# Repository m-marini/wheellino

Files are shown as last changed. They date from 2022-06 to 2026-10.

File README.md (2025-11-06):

Wheelly is a wheels robot.

The robot consits of

- Chassis with two lateral wheels driven by 2 x DC motors and a free wheel.
- 2 x IR speed sensors for the wheels
- Motor controller board L298N
- 12V DC rechargable motors Li battery
- 5V DC rechargable controller Li battery
- Power supply module 3.3V
- MPU6050 gyroscope module
- ESP32 Vroom main controller board
- SG90 Microservo
- 2 x Lidar sensors
- 6 x microswitch contact sensors
- LCD Display
- Wifi-Camera

The ESP32 controller is driving all the units to allow the robot to collect the sensor data, compute the position relative the initial state, drive the proxcimity sensor direction, drive the robot for a specific direction and speed by feeding back from gyroscpe and speed sensors and comunicate with remote server via wifi sending status and receiving commands.

Documentation in [Wiki](https://github.com/m-marini/wheellino/wiki)

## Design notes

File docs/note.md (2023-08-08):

# Note

Progetti di test:

- [x] Test MPU
- [x] Test Servo
- [x] Test Sensore SR04
- [ ] Test Motori + sensori motori
- [ ] Test sensori di contatto
- [ ] Test Display

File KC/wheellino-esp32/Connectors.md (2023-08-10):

# Connectors

### J1 - SR04 Proximity Sensor

| PIN |  Color | Description |
|----:|---|---|
| 1 | Yellow | 5V |
| 2 | Orange | Trigger |
| 3 | Red | Echo |
| 4 | Brown  | Gnd |

### J2 - Servo

| PIN |  Color | Description |
|----:|---|---|
| 1 | Brown  | Gnd |
| 2 | Red | 5V |
| 3 | Orange | PWM |

### J3 - Motor Drivers

| PIN |  Color | Description |
|----:|---|---|
| 1 | Brown  | LF |
| 2 | Red | 5V |
| 3 | Orange | LB |
| 4 | Yellow | Gnd |
| 5 | Green  | RB |
| 6 | Blue | Gnd |
| 7 | Purple | RF |
| 8 | White  | 5V |

### J4 - Wheels sensors

| PIN |  Color | Description |
|----:|---|---|
| 1 | Orange | 3V3 |
| 2 | White  | 3V3 |
| 3 | Yellow | Gnd |
| 4 | Purple | Gnd |
| 5 | Green  | Left |
| 6 | Blue | Right |

### J5 - Contact sensors

| PIN |  Color | Description |
|----:|---|---|
| 1  | Red | Rear |
| 2  | Brown  | Gnd |
| 3  | White  | Front |
| 4  | Blue | Gnd |

### J6 - 12V

| PIN |  Color | Description |
|----:|---|---|
| 1 | | 12V |
| 2 | | Gnd |
| 3 | | 12V |
| 4 | | Gnd |
| 5 | | 12V |
| 6 | | Gnd |

### J7 - 5V

| PIN |  Color | Description |
|----:|---|---|
| 1 | | 5V |
| 2 | | Gnd |
| 3 | | 5V |
| 4 | | Gnd |
| 5 | | 5V |
| 6 | | Gnd |

### J8 - GY521 Gyroscope

| PIN |  Color | Description |
|----:|---|---|
| 1 | | 3V3 |
| 2 | | Gnd |
| 3 | | SCL |
| 4 | | SDA |
| 5 | | XDA |
| 6 | | XCL |
| 6 | | INT |

### J9 - LCD

| PIN |  Color | Description |
|----:|---|---|
| 1 | Orange | SCL |
| 2 | Yellow | SDA |
| 3 | Green  | 5V |
| 4 | Blue | Gnc |

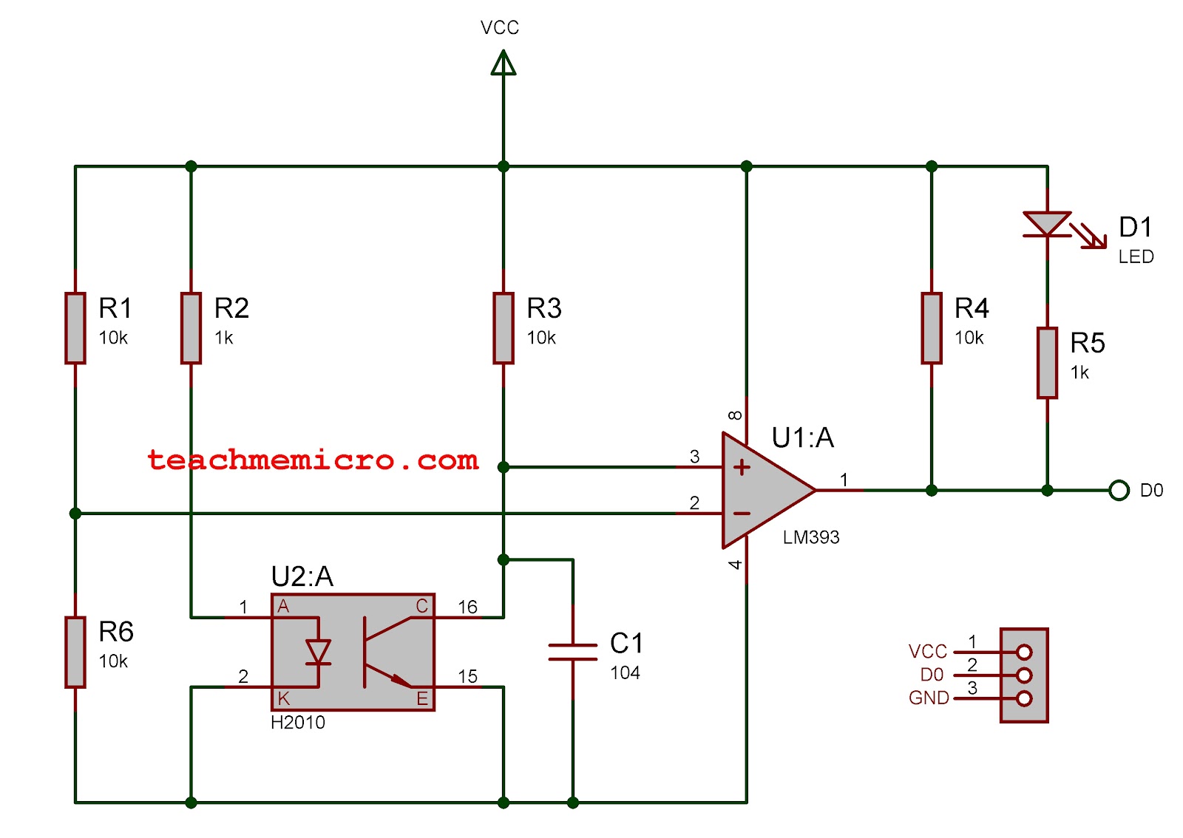
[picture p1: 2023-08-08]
docs/lm393-speed-sensor-schematic.jpg

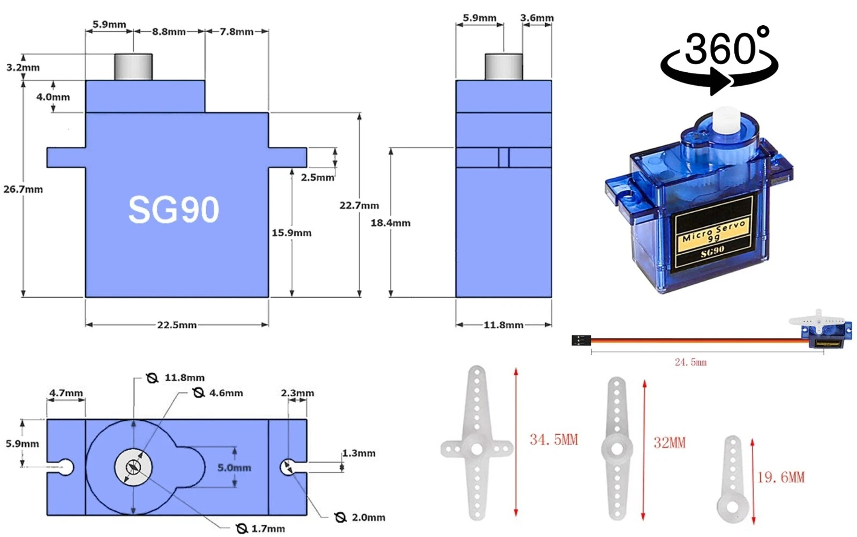
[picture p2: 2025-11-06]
docs/sg90.webp

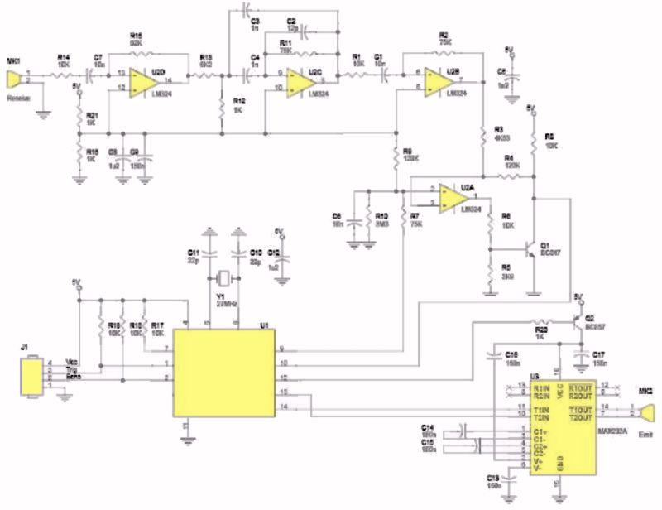
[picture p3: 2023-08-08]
docs/HC-SR04-ultrasonic-module.jpg

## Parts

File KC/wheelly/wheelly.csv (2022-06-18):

Source: | D:\git\wheelly\KC\wheelly\wheelly.kicad_sch
Date: | 31/01/2022 01:18:20
Tool: | Eeschema (6.0.1)
Generator: | C:\Program Files\KiCad\6.0\bin\scripting\plugins/bom_csv_grouped_by_value_with_fp.py
Component Count: | 43
Ref | Qnty | Value | Cmp name | Footprint | Description | Vendor
D1, D2, D3, D4, | 4 | Red | LED_Small_Filled |  | Light emitting diode, small symbol, filled shape
D5, D7, | 2 | Green | LED_Small_Filled |  | Light emitting diode, small symbol, filled shape
D6, | 1 | Yellow | LED_Small_Filled |  | Light emitting diode, small symbol, filled shape
D8, | 1 | Ywllow | LED_Small_Filled |  | Light emitting diode, small symbol, filled shape
D9, D10, D11, D12, D13, D14, D15, D16, | 8 | 1N4001 | 1N4001 | Diode_THT:D_DO-41_SOD81_P10.16mm_Horizontal | 50V 1A General Purpose Rectifier Diode, DO-41
K1, K2, K3, K4, | 4 | FINDER-36.11 | FINDER-36.11 | Relay_THT:Relay_SPDT_Finder_36.11 | FINDER 36.11, SPDT relay, 10A
M1, M3, | 2 | Motor_DC | Motor_DC |  | DC Motor
M2, | 1 | Motor_Servo_Grapner_JR | Motor_Servo_Grapner_JR |  | Servo Motor (Graupner JR connector)
P1, | 1 | Power | Conn_01x08 | Socket_Arduino_Uno:Socket_Strip_Arduino_1x08 | Generic connector, single row, 01x08, script generated (kicad-library-utils/schlib/autogen/connector/)
P2, | 1 | Analog | Conn_01x06 | Socket_Arduino_Uno:Socket_Strip_Arduino_1x06 | Generic connector, single row, 01x06, script generated (kicad-library-utils/schlib/autogen/connector/)
P3, | 1 | Digital | Conn_01x10 | Socket_Arduino_Uno:Socket_Strip_Arduino_1x10 | Generic connector, single row, 01x10, script generated (kicad-library-utils/schlib/autogen/connector/)
P4, | 1 | Digital | Conn_01x08 | Socket_Arduino_Uno:Socket_Strip_Arduino_1x08 | Generic connector, single row, 01x08, script generated (kicad-library-utils/schlib/autogen/connector/)
P5, P6, P7, P8, | 4 | CONN_01X01 | Conn_01x01 | Socket_Arduino_Uno:Arduino_1pin | Generic connector, single row, 01x01, script generated (kicad-library-utils/schlib/autogen/connector/)
R1, R2, R3, R4, R5, R6, R7, R8, | 8 | 1K | R |  | Resistor
U1, | 1 | 74HC595 | 74HC595 |  | 8-bit serial in/out Shift Register 3-State Outputs
U2, | 1 | L293D | L293D | Package_DIP:DIP-16_W7.62mm | Quadruple Half-H Drivers
U3, | 1 | TSDP341xx | TSDP341xx | OptoDevice:Vishay_MOLD-3Pin | IR Receiver Modules for Data Transmission
U4, | 1 | SR04 | SR04

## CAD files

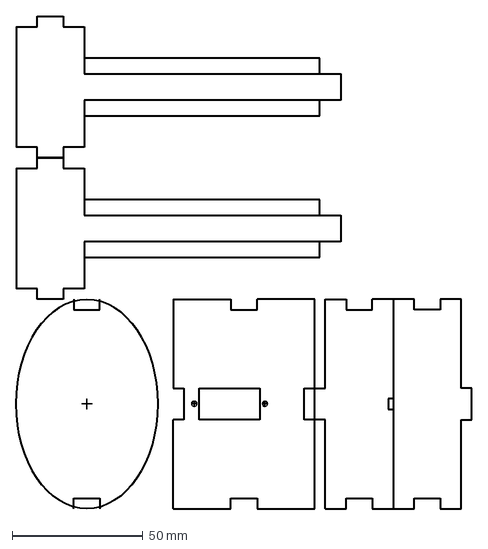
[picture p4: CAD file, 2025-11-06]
CAD/HeadLift.dxf
174.0 x 188.0 mm

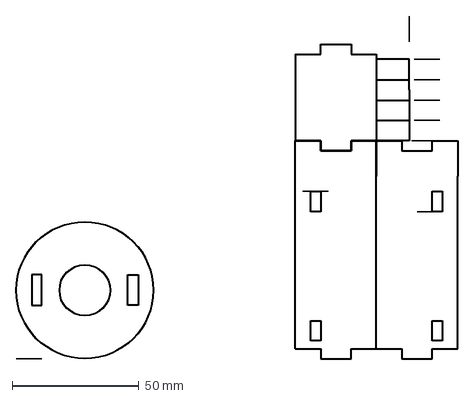
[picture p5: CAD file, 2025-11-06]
CAD/Head.dxf
174.0 x 135.0 mm

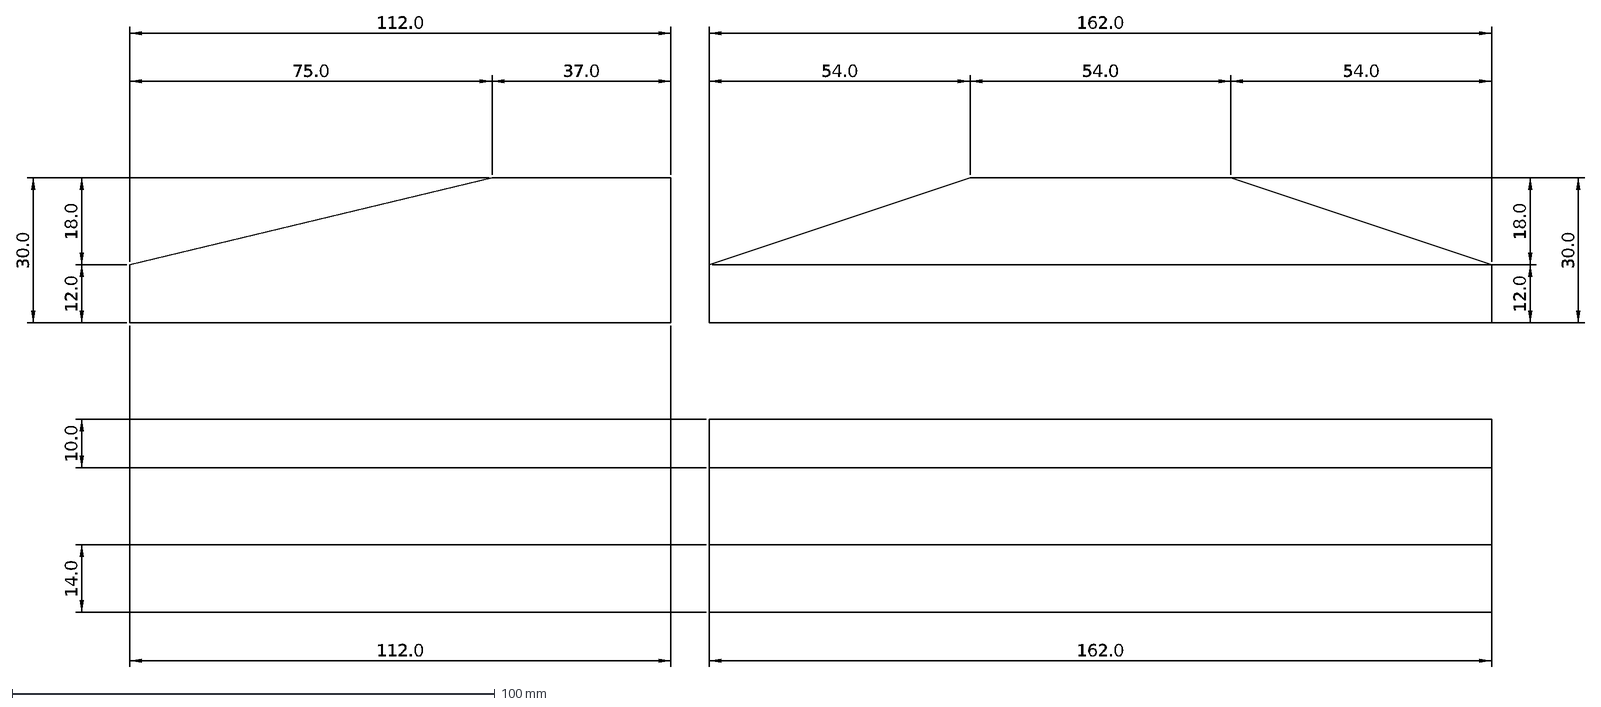
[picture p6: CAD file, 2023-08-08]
CAD/Contacts.dxf
112.0
10.0
14.0
75.0
37.0
12.0
30.0
18.0
54.0
162.0

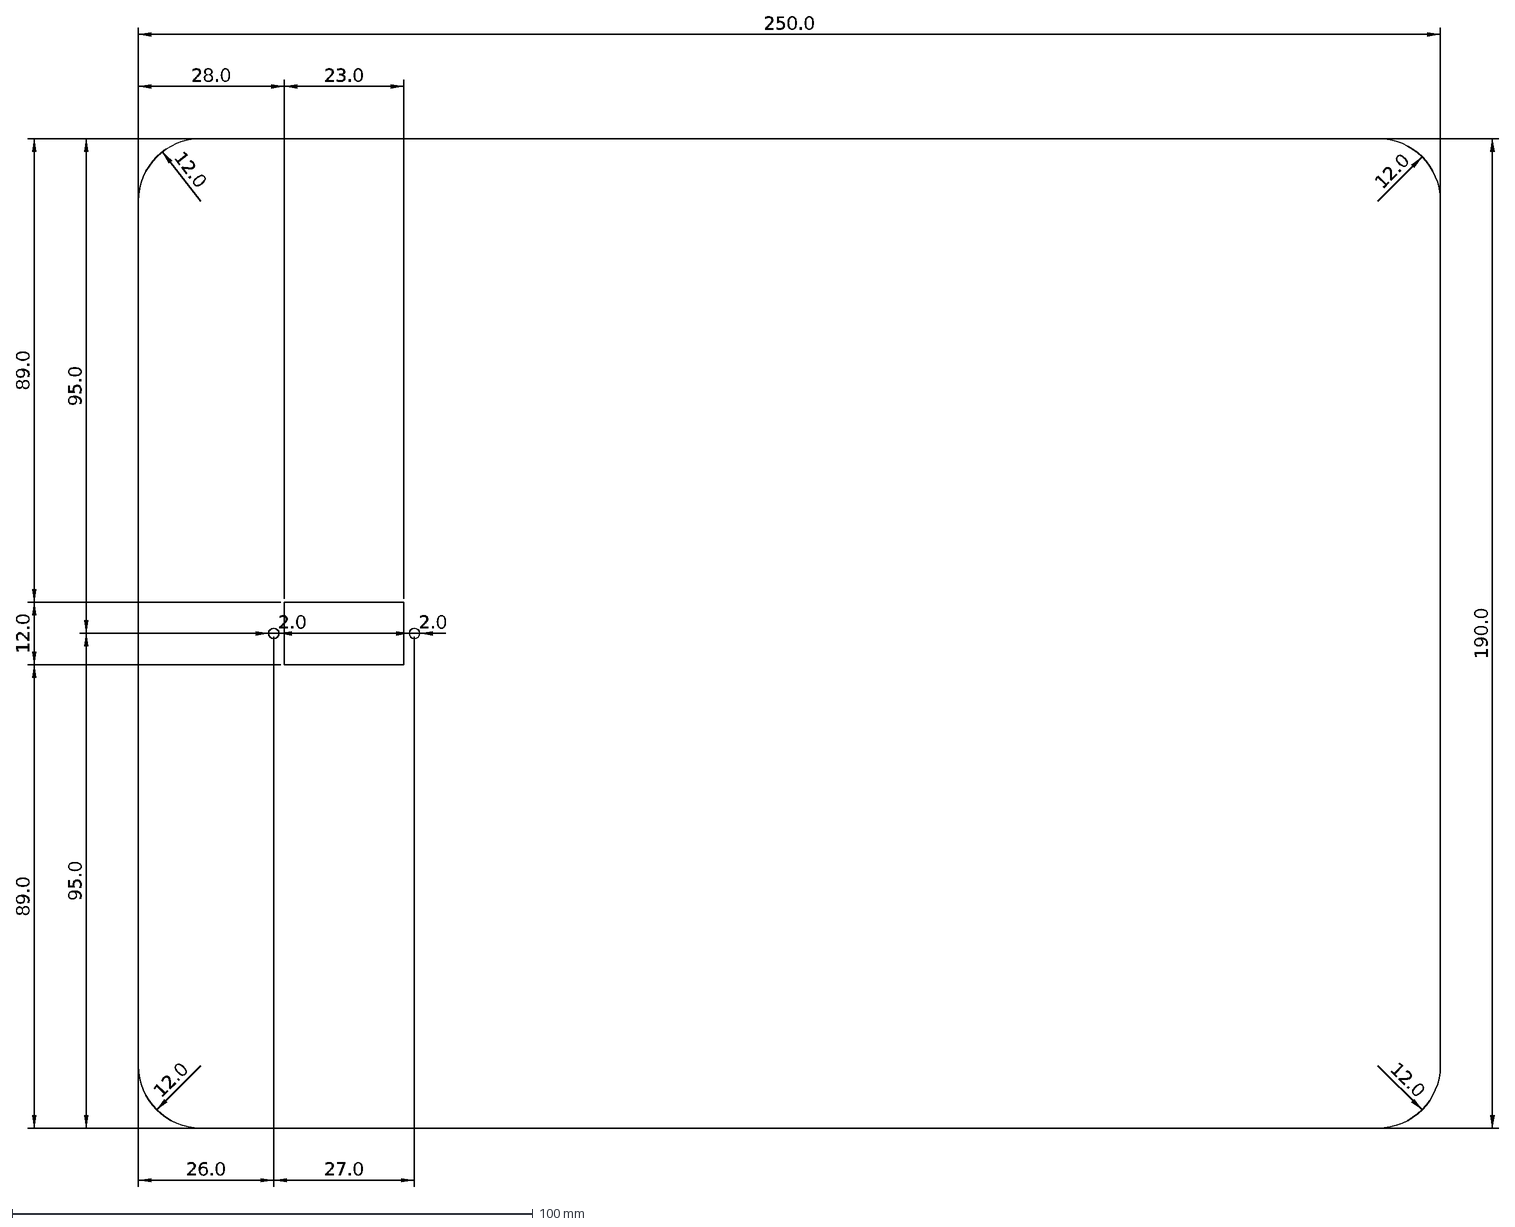
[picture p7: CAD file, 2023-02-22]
CAD/Base.dxf
12.0
28.0
23.0
26.0
27.0
95.0
89.0
190.0
250.0
2.0

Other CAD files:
Blender/2.0/Cam.blend
Blender/2.0/CamBoards.blend
Blender/2.0/Head-print.blend
Blender/2.0/Head.blend
Blender/2.0/HeadSup.blend
Blender/2.0/LidarsBoards.blend
Blender/2.0/SG90.blend
Blender/ArduinoBoard.blend
Blender/Base.blend
Blender/Breadboard.blend
Blender/LidarHead-print.blend
Blender/LidarHead.blend
Blender/MotorBase.blend
Blender/MotorBoard.blend
Blender/Prova.blend
Blender/SR04Sensor.blend
Blender/Supplier.blend
Blender/Wheelly.blend

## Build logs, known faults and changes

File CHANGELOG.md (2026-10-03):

# Changelog

All notable changes to this project will be documented in this file.

The format is based on [Keep a Changelog](http://keepachangelog.com/en/1.0.0/)
and this project adheres to [Semantic Versioning](http://semver.org/spec/v2.0.0.html).

## [Unreleased]

### Add

- Issue [#141](https://github.com/m-marini/wheellino/issues/141): Head absolute target command

## [0.11.0](https://github.com/m-marini/wheellino/releases/tag/v0.11.0)  2026-10-01

### Changed

- Issue [#130](https://github.com/m-marini/wheellino/issues/130): Add goto commands
- Issue [#134](https://github.com/m-marini/wheellino/issues/134): Motor controlled by time pulse

### Fixed

- Issue [#139](https://github.com/m-marini/wheellino/issues/139): Robot does not stop at target

## [0.10.0](https://github.com/m-marini/wheellino/releases/tag/v0.10.0) 2026-02-26

### Added

- Issue [#117](https://github.com/m-marini/wheellino/issues/117): Add Lidar sensors
- Issue [#124](https://github.com/m-marini/wheellino/issues/124): Add wheelly measure end test record
- Issue [#126](https://github.com/m-marini/wheellino/issues/126): Add supply measure in wheelly measures
- Issue [#128](https://github.com/m-marini/wheellino/issues/128): Add SD Camera Card and change motor controller by voltage
- Issue [#131](https://github.com/m-marini/wheellino/issues/131): Add Head rotation limits

### Changed

- Issue [#122](https://github.com/m-marini/wheellino/issues/122): Mqtt Wheelly measures
- Issue [#120](https://github.com/m-marini/wheellino/issues/120): Change motor controller

## [0.9.0] 2025-10-06

### Added

- Issue [#113](https://github.com/m-marini/wheellino/issues/113): Add MQTT architecture

## [0.8.1] 2025-08-11

### Changed

- Issue [#111](https://github.com/m-marini/wheellino/issues/111): ESP 32 board 3.2.1
- Issue [#104](https://github.com/m-marini/wheellino/issues/104): Averaging supply measures
- Issue [#107](https://github.com/m-marini/wheellino/issues/107): Add Web Camera

## [0.8.0] 2023-12-14

### Changed

- Issue #98: Add asyncronous status messages
- Issue #100: Smooth proxy sensor movement

### Fixed

- Issue #98: Sync timeout on reconnection

## [0.7.1] 2023-12-08

### Changed

- Issue #91: Change LED status flashing
- Issue #93: Switch on LED until start

### Fixed

- Issue #95: Unexpetcted restart on servo movement
- Issue #99: Sync timeout on reconnection

## [0.7.0] 2023-11-12

### Added

- Issue #78: Add friction test
- Issue #84: Add battery level icons
- Issue #86: Add proxy sensor noise filter
- Issue #88: Fix status send frequence on move (TCS review)

### Changed

- Issue #75: Change motion by mixing rotation and movement
- Issue #80: Change stiction and friction test

### Removed

- Issue #82: Remove arduino one board code

## [0.6.1] 2023-10-20

### Added

- Issue #55: Add configure proxy scan interval
- Issue #69: Add physic measures

### Changed

- Issue #71: Change measures with power ramp up and down

### Fixed

- Issue #61: Bug Wifi post config dump
- Issue #64: API get networks list often run in Guru meditation
- Issue #67: Yaw drift
- Issue #73: Fix report with start and stop test records

## [0.6.0] 2023-08-22

### Added

- Issue #47: WheellyESP32

### Changed

- Issue #36: Change motor controller to manage stiction
- Issue #42: Merge filter and speedmeter
- Issue #44: Add power acceleration limits
- Issue #46: New larger base, contact bars and control board

### Fixed

- Issue #38: Error at cl command
- Issue #40: Error parsing cm command

## [0.4.1] 2023-02-09

### Added

- Issue #32: Limit robot angular speed

### Changed

- Issue #34: Change WheellyMeasures to run ramp power measures

## [0.4.0] 2023-02-07

### Added

- Issue #30: Set contact sensors thresholds

## [0.3.2] 2023-01-25

### Fixed

- Isssue #27: Configuration command error

## [0.3.1] 2023-01-20

### Changed

- Issue #22: Change WheellyMeasures
- Issue #24: Change motor power supply and add controller configurations

## [0.3.0] 2023-01-08

### Changed

- Issue #19: Minimal data conversion

## [0.2.5] 2023-01-08

### Added

- Issue #16: Add movement check up
- Issue #15: Bad gyroscope measure moving

## [0.2.4] 2022-09-12

### Added

- Issue #13: Add GET network configuration api

## [0.2.3] 2022-09-12

### Added

- Issue #11: status led for default access point

## [0.2.2] 2022-08-14

### Fixed

- Issue #9: MPU failure bug

## [0.2.1] 2022-07-16

### Fixed

- Issue #7: Standard reference system

## [0.2.0] 2022-07-15

### Changed

- Issue #5: Changed startup led sequence and output wifi IP Address

## [0.1.2] 2022-06-17

### Added

- Issue #1: Release 0.1.2

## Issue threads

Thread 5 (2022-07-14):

Changed startup led sequence and output wifi IP Address

m-marini, 2022-07-14:
The new sequence is
- Starting: RED pulse
- Init IMU: RED
- Init servo: YELLOW pulse
- Reset IMU: YELLOW pulse
- Ready: GREEN pulse

Closed 2022-07-14.

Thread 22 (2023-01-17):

Change WheellyMeasures

m-marini, 2023-01-17:
Remove theta correction factor from wheelly measure.

Closed 2023-01-17.

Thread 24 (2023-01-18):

Change motor power supply

m-marini, 2023-01-18:
Change the power supply to 12V and the motor power controller to manage the new supply power

Closed 2023-01-20.

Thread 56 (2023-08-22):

Connection timeout with ESP32

m-marini, 2023-08-22:

m-marini, 2023-10-20:
it doesn't happen anymore

Closed 2023-10-20.

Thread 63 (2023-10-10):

Wrong yaw  during movement

m-marini, 2023-10-10:
During movement (e.g. rotation) the yaw change in wrong manner (the read robot direction is not the real direction 20DEG -> -150DEG)

m-marini, 2023-10-20:
Fixed with issue #67 - Yaw drift

Closed 2023-10-20.

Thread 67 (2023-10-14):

Yaw drift

m-marini, 2023-10-14:

Closed 2023-10-16.

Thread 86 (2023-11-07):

Add proxy sensor noise filter

m-marini, 2023-11-07:

Closed 2023-11-07.

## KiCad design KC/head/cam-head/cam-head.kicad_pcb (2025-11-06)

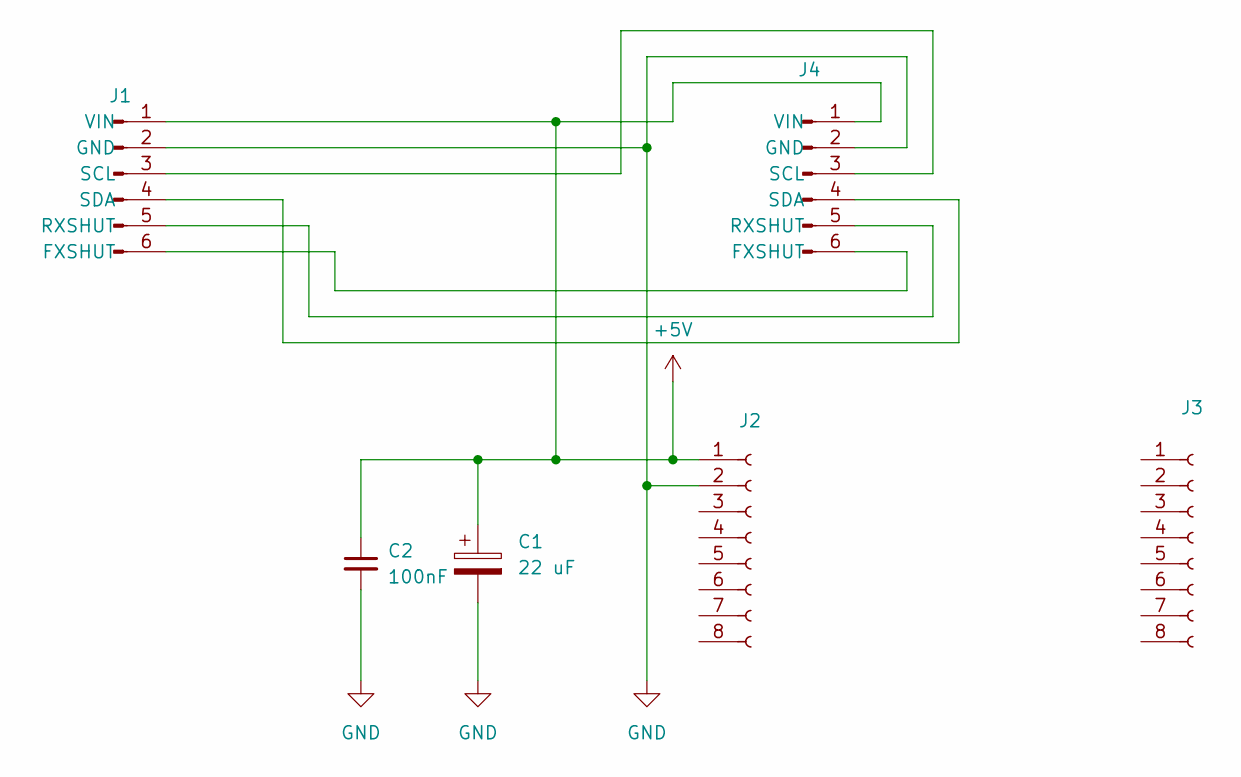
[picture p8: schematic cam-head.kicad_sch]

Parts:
C1: 22 uF; CP_Radial_D5.0mm_P2.50mm
C2: 100nF; C_Rect_L7.0mm_W2.5mm_P5.00mm
J1: Conn_01x06_Pin; PinHeader_1x06_P2.54mm_Horizontal
J2, J3: Conn_01x08_Socket; PinSocket_1x08_P2.54mm_Vertical
J4: Conn_01x06_Pin; PinHeader_1x06_P2.54mm_Vertical

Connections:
+5V: C1.1, C2.1, J1.1 (VIN), J2.1, J4.1 (VIN)
GND: C1.2, C2.2, J1.2 (GND), J2.2, J4.2 (GND)
unnamed: J1.6 (FXSHUT), J4.6 (FXSHUT)
unnamed: J1.5 (RXSHUT), J4.5 (RXSHUT)
unnamed: J1.3 (SCL), J4.3 (SCL)
unnamed: J1.4 (SDA), J4.4 (SDA)

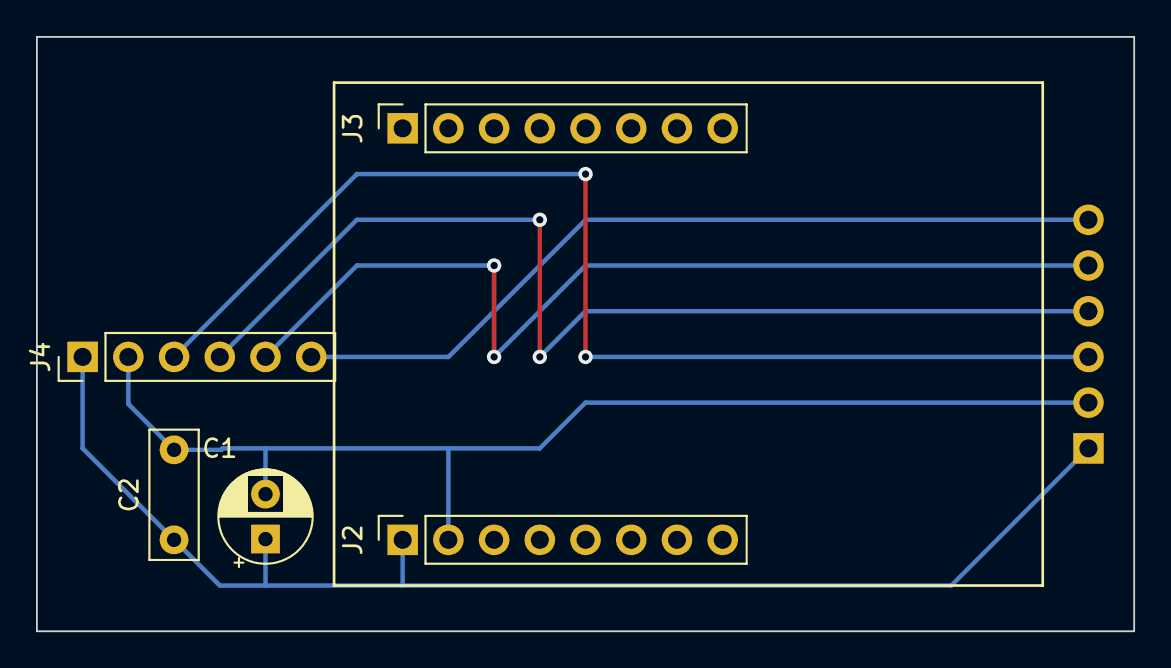
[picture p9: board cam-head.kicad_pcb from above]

Board: 2 copper layers, 61.0 x 33.0 mm, 6 parts (1 on the bottom side), 6 nets.

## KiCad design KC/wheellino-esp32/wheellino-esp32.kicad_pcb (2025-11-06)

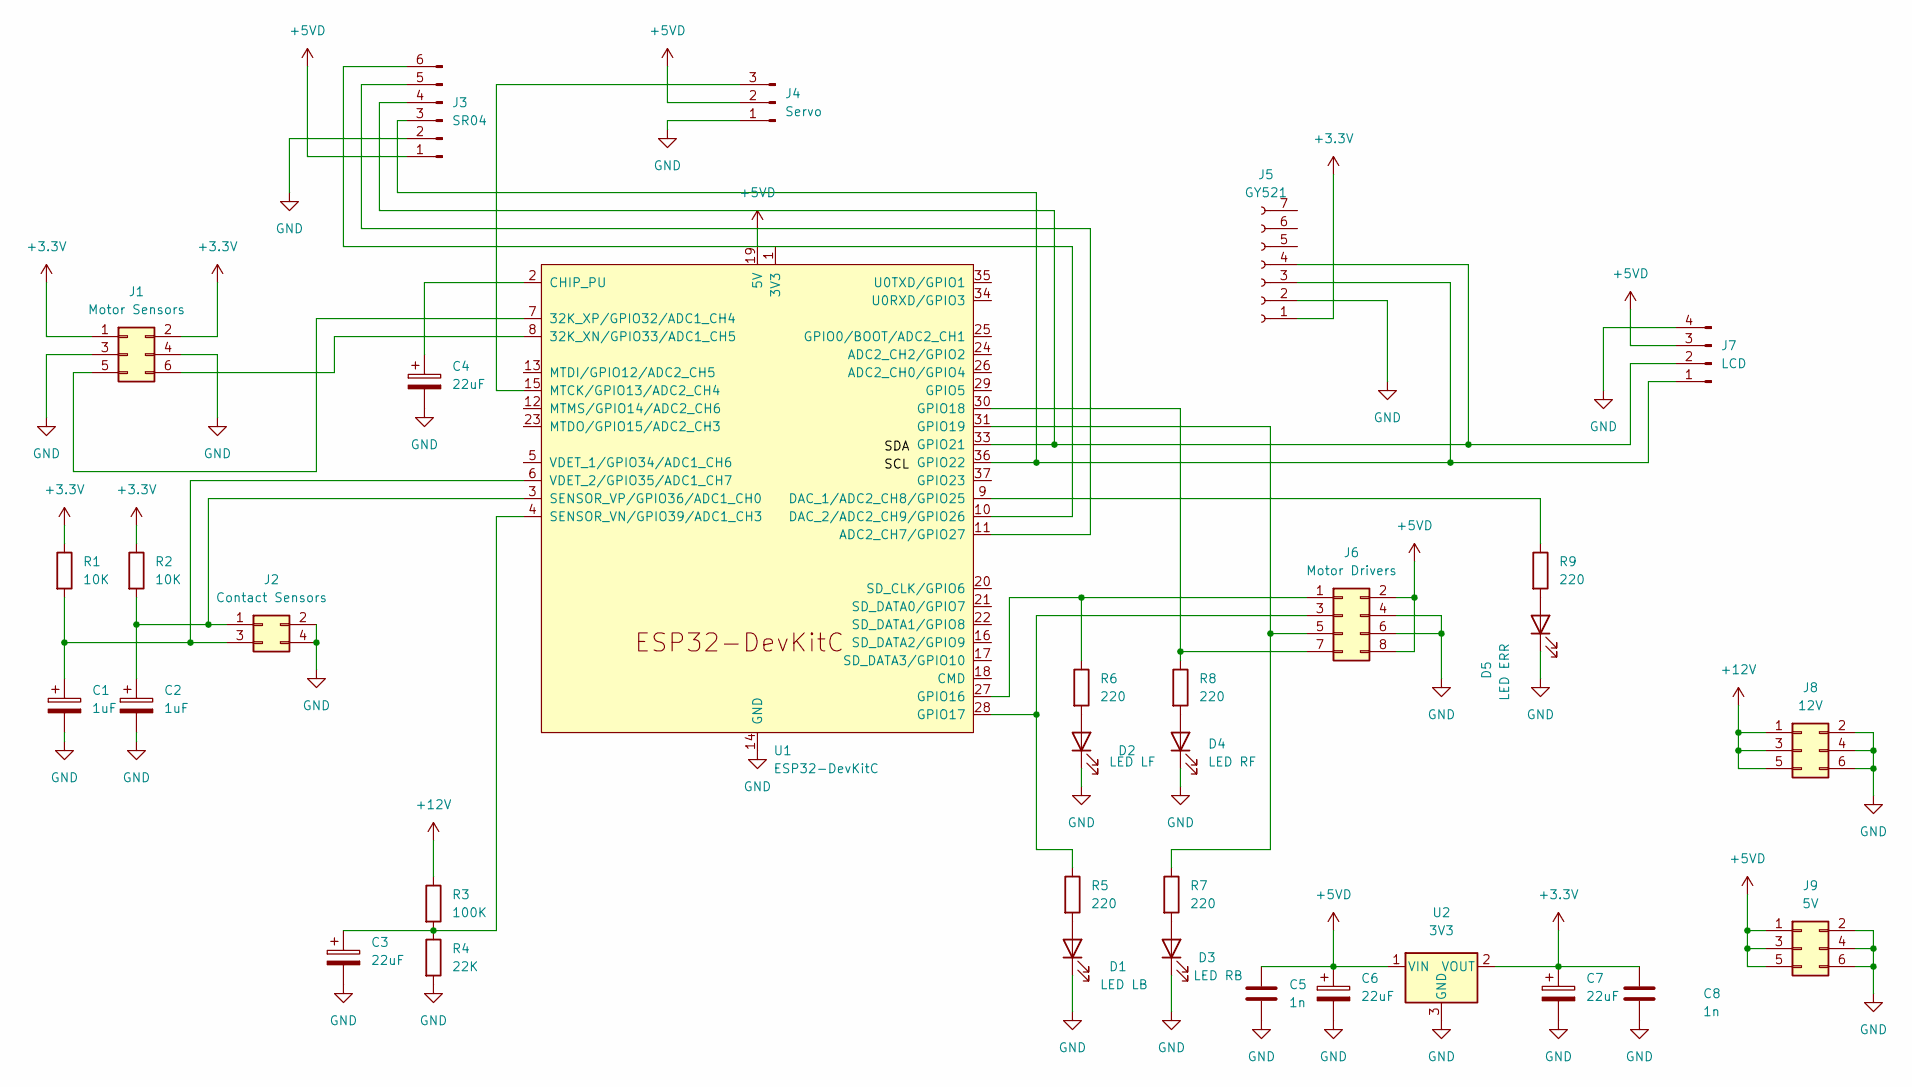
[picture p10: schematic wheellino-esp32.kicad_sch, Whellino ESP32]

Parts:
C1, C2: 1uF; CP_Radial_D5.0mm_P2.50mm
C3, C4, C6, C7: 22uF; CP_Radial_D5.0mm_P2.50mm
C5, C8: 1n; C_Rect_L7.0mm_W2.0mm_P5.00mm
D1: LED LB; LED_D5.0mm
D2: LED LF; LED_D5.0mm
D3: LED RB; LED_D5.0mm
D4: LED RF; LED_D5.0mm
D5: LED ERR; LED_D5.0mm
J1: Motor Sensors; PinHeader_2x03_P2.54mm_Vertical
J2: Contact Sensors; PinHeader_2x02_P2.54mm_Vertical
J3: SR04; PinHeader_1x06_P2.54mm_Vertical
J4: Servo; PinHeader_1x03_P2.54mm_Vertical
J5: GY521; PinSocket_1x08_P2.54mm_Vertical
J6: Motor Drivers; PinHeader_2x04_P2.54mm_Vertical
J7: LCD; PinHeader_1x04_P2.54mm_Vertical
J8: 12V; PinHeader_2x03_P2.54mm_Vertical
J9: 5V; PinHeader_2x03_P2.54mm_Vertical
R1, R2: 10K; R_Axial_DIN0207_L6.3mm_D2.5mm_P10.16mm_Horizontal
R3: 100K; R_Axial_DIN0207_L6.3mm_D2.5mm_P10.16mm_Horizontal
R4: 22K; R_Axial_DIN0207_L6.3mm_D2.5mm_P10.16mm_Horizontal
R5, R6, R7, R8, R9: 220; R_Axial_DIN0207_L6.3mm_D2.5mm_P10.16mm_Horizontal
U1: ESP32-DevKitC; ESP32
U2: 3V3; PinHeader_1x03_P2.54mm_Vertical

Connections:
+3V3: C7.1, C8.1, J1.1, J1.2, J5.1, R1.1, R2.1, U2.2 (VOUT)
+12V: J8.1, J8.3, J8.5, R3.1
GND: C1.2, C2.2, C3.2, C4.2, C5.2, C6.2, C7.2, C8.2, D1.1 (K), D2.1 (K), D3.1 (K), D4.1 (K), D5.1 (K), J1.3, J1.4, J2.2, J2.4, J3.2, J4.1, J5.2, J6.4, J6.6, J7.4, J8.2, J8.4, J8.6, J9.2, J9.4, J9.6, R4.2, U1.14 (GND), U1.32 (GND), U1.38 (GND), U2.3 (GND)
unnamed: D1.2 (A), R5.2
unnamed: D2.2 (A), R6.2
unnamed: D3.2 (A), R7.2
unnamed: D4.2 (A), R8.2
unnamed: D5.2 (A), R9.2
unnamed: J1.5, U1.7 (32K_XP/GPIO32/ADC1_CH4)
unnamed: J1.6, U1.8 (32K_XN/GPIO33/ADC1_CH5)
unnamed: C2.1, J2.1, R2.2, U1.3 (SENSOR_VP/GPIO36/ADC1_CH0)
unnamed: C1.1, J2.3, R1.2, U1.6 (VDET_2/GPIO35/ADC1_CH7)
unnamed: J3.3, J5.3, J7.1, U1.36 (GPIO22)
unnamed: J3.4, J5.4, J7.2, U1.33 (GPIO21)
unnamed: J3.6, U1.10 (DAC_2/ADC2_CH9/GPIO26)
unnamed: J4.3, U1.15 (MTCK/GPIO13/ADC2_CH4)
unnamed: J6.1, R6.1, U1.27 (GPIO16)
unnamed: J6.3, R5.1, U1.28 (GPIO17)
unnamed: J6.5, R7.1, U1.31 (GPIO19)
unnamed: J6.7, R8.1, U1.30 (GPIO18)
unnamed: C4.1, U1.2 (CHIP_PU)
unnamed: R9.1, U1.9 (DAC_1/ADC2_CH8/GPIO25)
unnamed: C3.1, R3.2, R4.1, U1.4 (SENSOR_VN/GPIO39/ADC1_CH3)

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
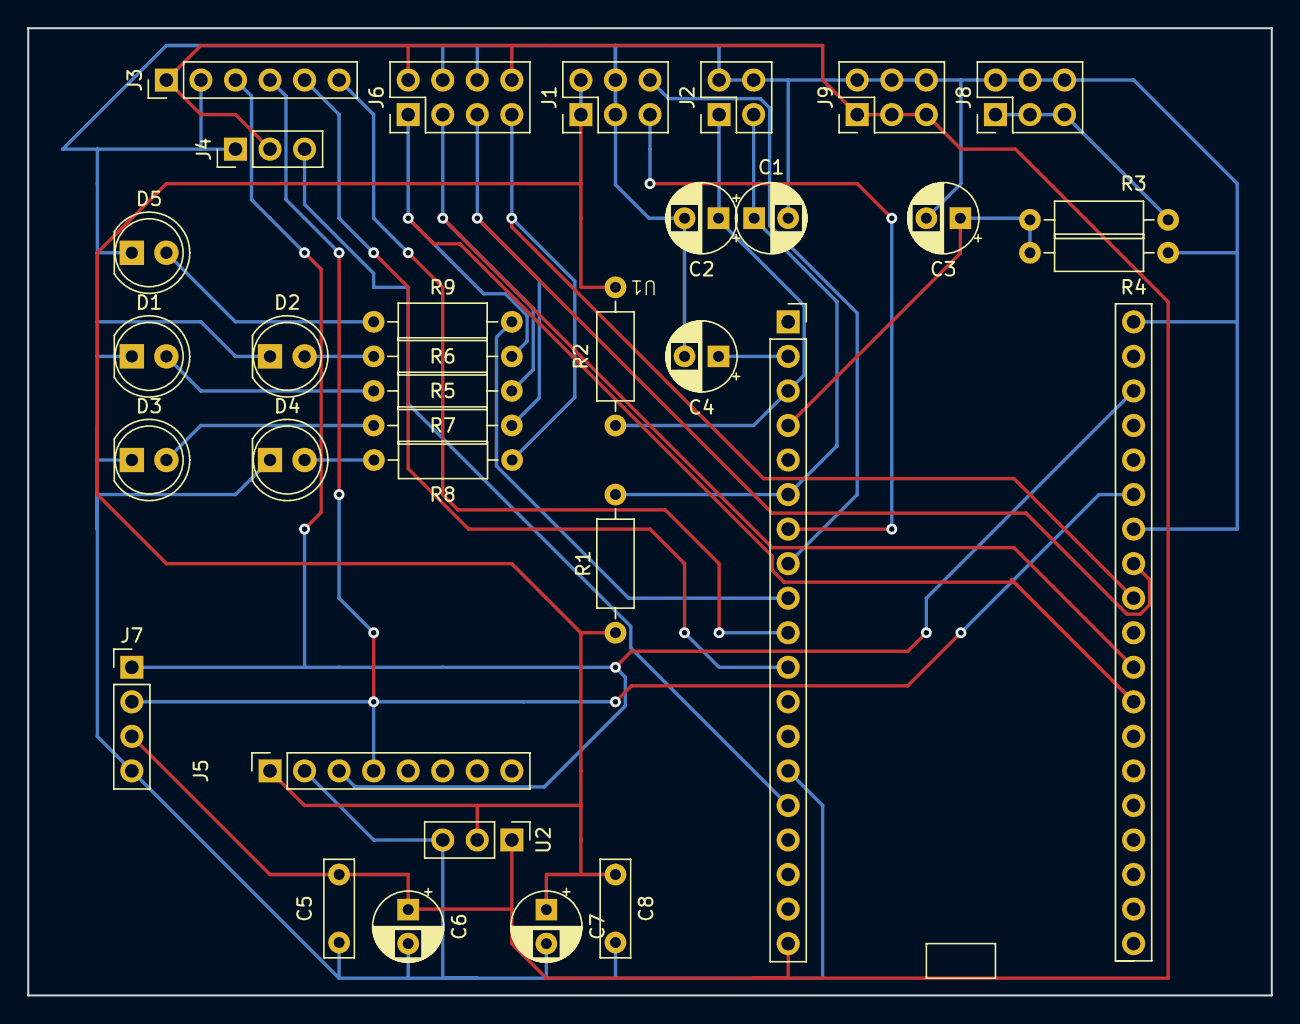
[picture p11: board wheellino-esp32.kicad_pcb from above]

Board: 2 copper layers, 91.4 x 71.1 mm, 33 parts (0 on the bottom side), 25 nets.

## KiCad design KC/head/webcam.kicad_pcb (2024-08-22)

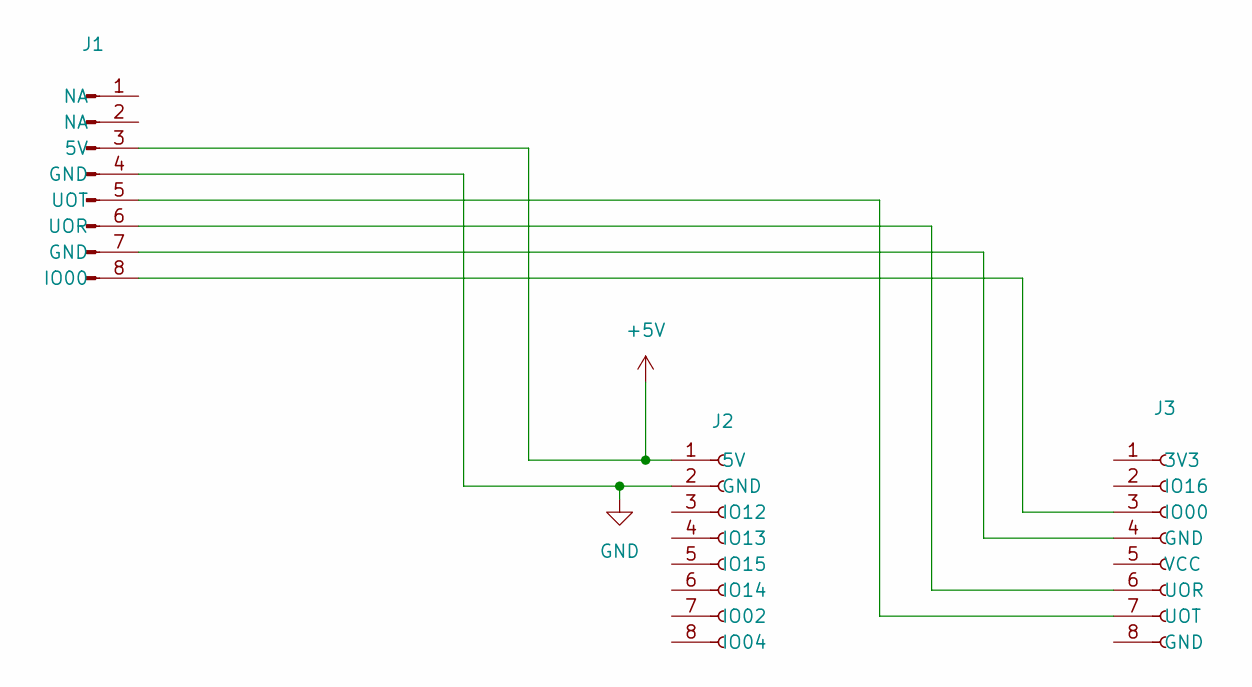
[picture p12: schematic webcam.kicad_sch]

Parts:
J1: Conn_01x08_Pin; PinHeader_1x08_P2.54mm_Horizontal
J2, J3: Conn_01x08_Socket; PinSocket_1x08_P2.54mm_Vertical

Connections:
+5V: J1.3 (5V), J2.1 (5V)
GND: J1.4 (GND), J2.2 (GND)
unnamed: J1.7 (GND), J3.4 (GND)
unnamed: J1.8 (IO00), J3.3 (IO00)
unnamed: J1.6 (UOR), J3.6 (UOR)
unnamed: J1.5 (UOT), J3.7 (UOT)

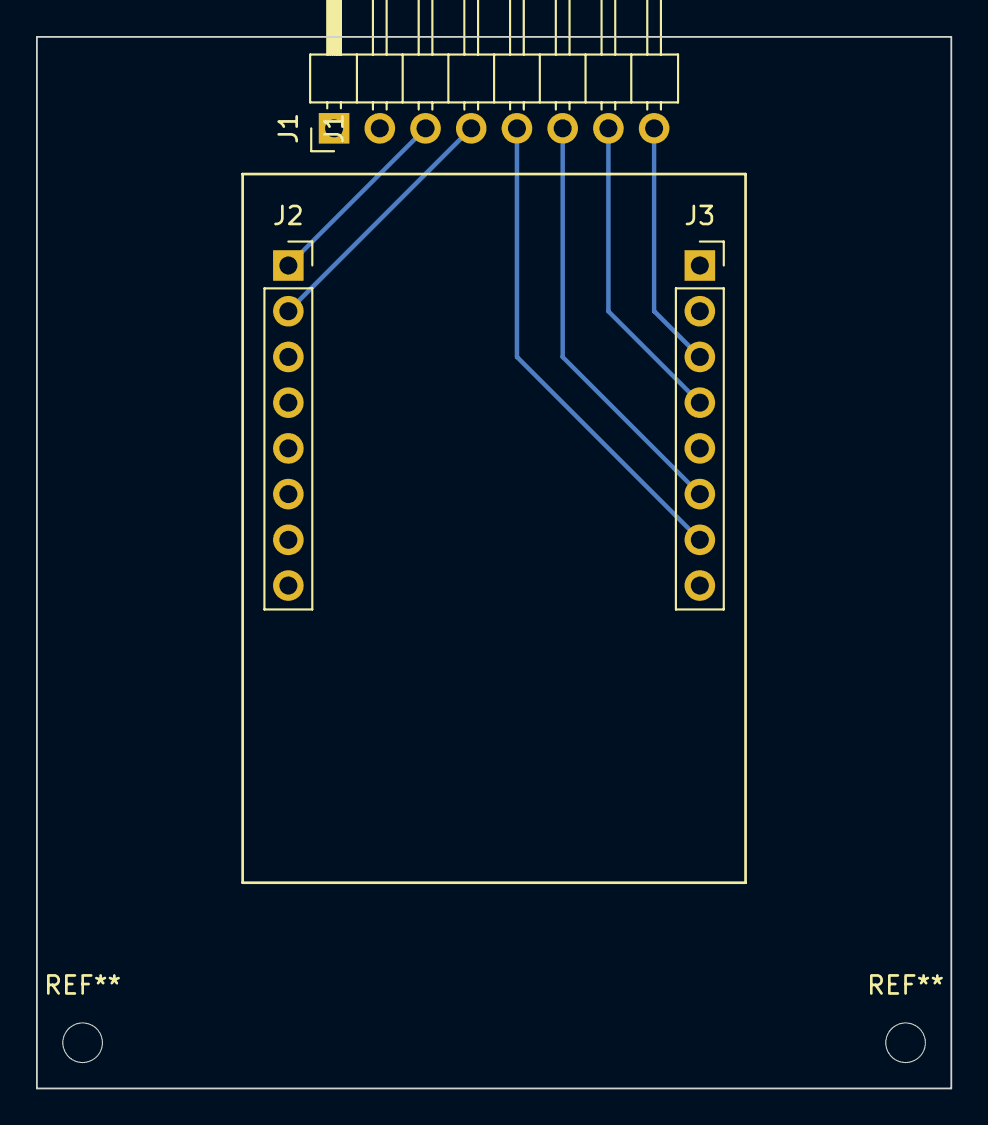
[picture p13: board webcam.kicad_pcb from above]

Board: 2 copper layers, 50.8 x 58.4 mm, 3 parts (0 on the bottom side), 6 nets.

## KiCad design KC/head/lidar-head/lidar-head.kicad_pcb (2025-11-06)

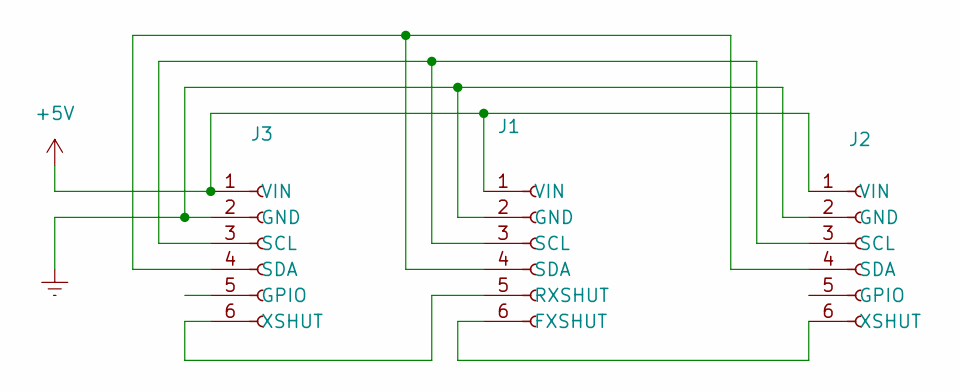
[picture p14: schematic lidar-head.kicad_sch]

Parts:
J1, J2, J3: Conn_01x06_Socket; PinSocket_1x06_P2.54mm_Vertical

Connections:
+5V: J1.1 (VIN), J2.1 (VIN), J3.1 (VIN)
Earth: J1.2 (GND), J2.2 (GND), J3.2 (GND)
unnamed: J1.6 (FXSHUT), J2.6 (XSHUT)
unnamed: J1.5 (RXSHUT), J3.6 (XSHUT)
unnamed: J1.3 (SCL), J2.3 (SCL), J3.3 (SCL)
unnamed: J1.4 (SDA), J2.4 (SDA), J3.4 (SDA)

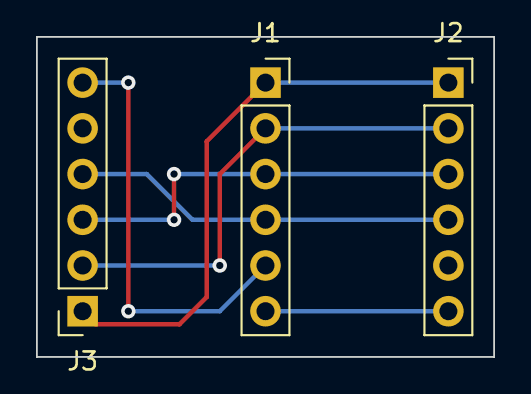
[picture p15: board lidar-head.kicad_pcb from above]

Board: 2 copper layers, 25.4 x 17.8 mm, 3 parts (0 on the bottom side), 6 nets.

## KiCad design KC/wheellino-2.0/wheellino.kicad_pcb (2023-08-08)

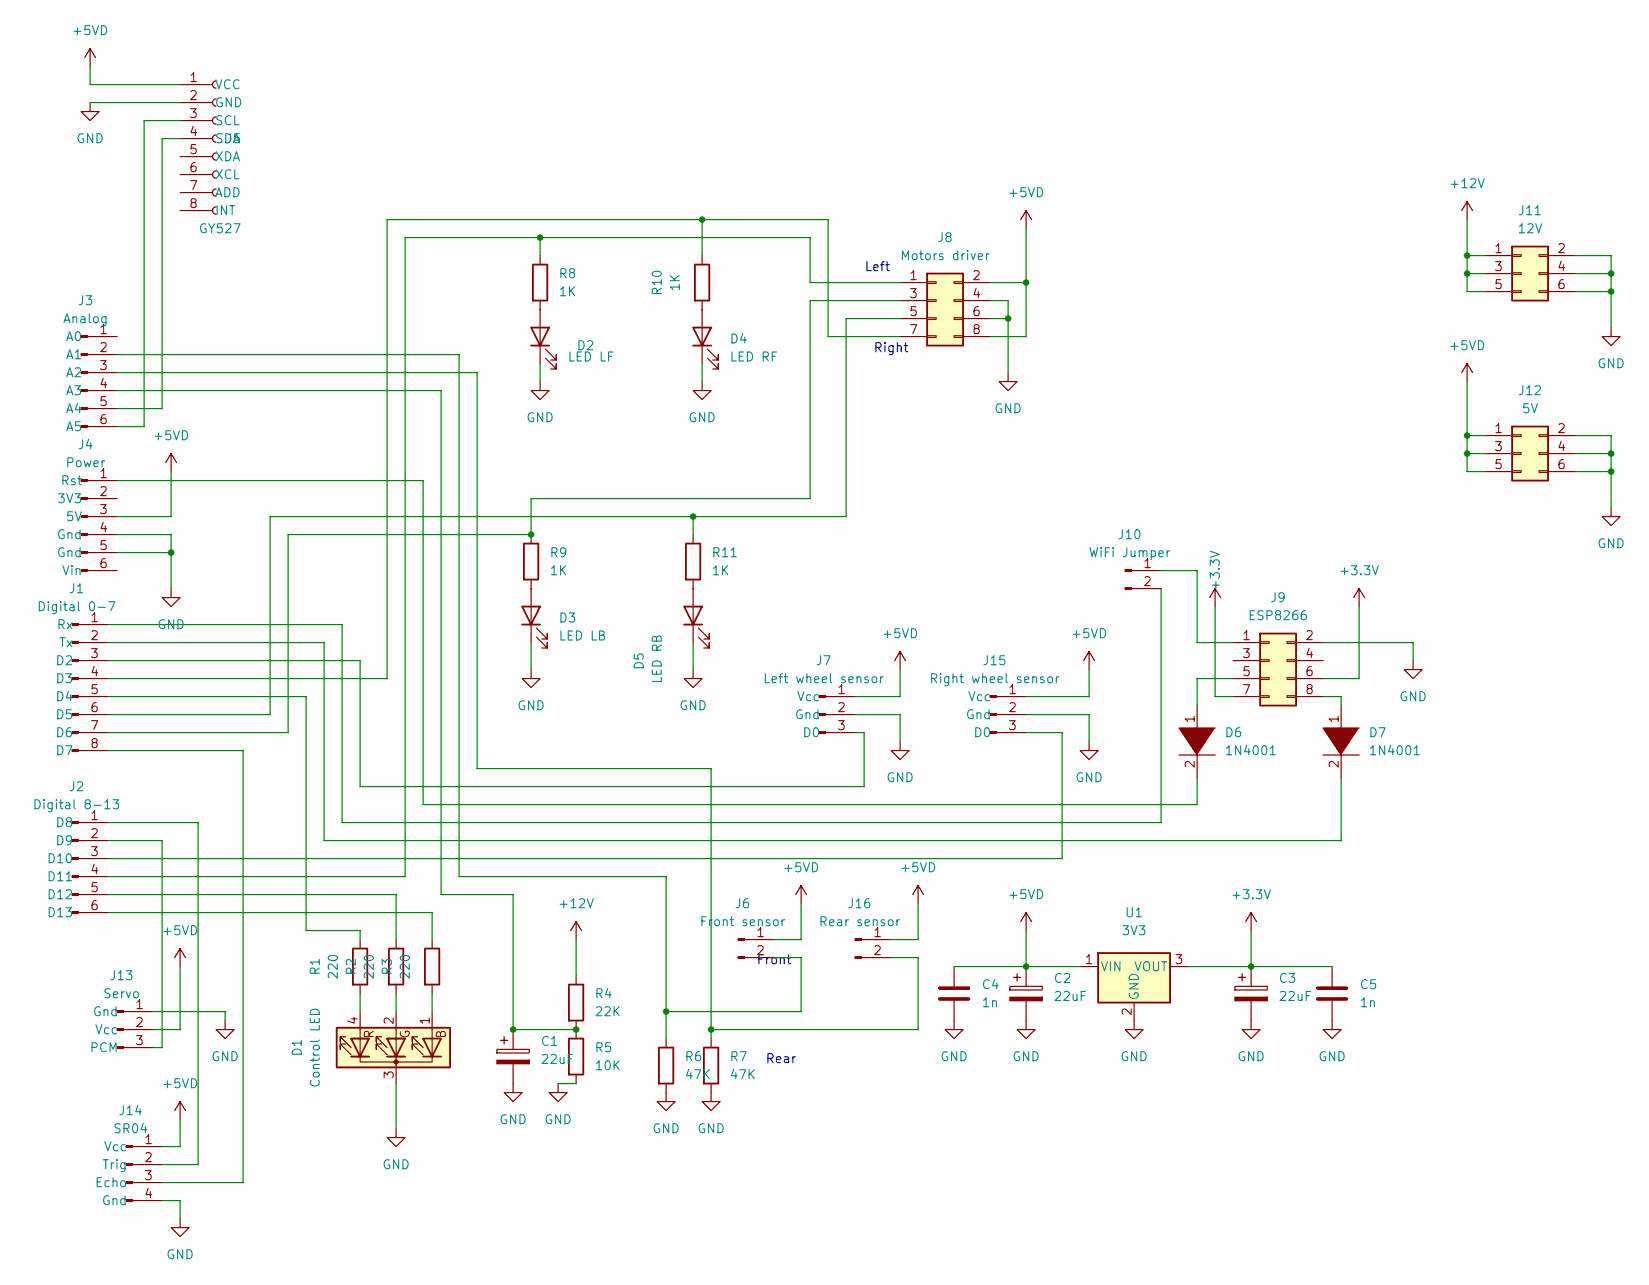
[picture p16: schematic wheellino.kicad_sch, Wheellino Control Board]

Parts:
C1, C2, C3: 22uF; CP_Radial_D5.0mm_P2.50mm
C4, C5: 1n; C_Rect_L7.0mm_W2.0mm_P5.00mm
D1: Control LED; LED_D5.0mm-4_RGB_Wide_Pins
D2: LED LF; LED_D5.0mm
D3: LED LB; LED_D5.0mm
D4: LED RF; LED_D5.0mm
D5: LED RB; LED_D5.0mm
D6, D7: 1N4001; D_DO-41_SOD81_P10.16mm_Horizontal
J1: Digital 0-7; PinHeader_1x08_P2.54mm_Vertical
J2: Digital 8-13; PinHeader_1x06_P2.54mm_Vertical
J3: Analog; PinHeader_1x06_P2.54mm_Vertical
J4: Power; PinHeader_1x06_P2.54mm_Vertical
J5: GY527; PinSocket_1x08_P2.54mm_Vertical
J6: Front sensor; PinHeader_1x02_P2.54mm_Vertical
J7: Left wheel sensor; PinHeader_1x03_P2.54mm_Vertical
J8: Motors driver; PinHeader_2x04_P2.54mm_Vertical
J9: ESP8266; PinHeader_2x04_P2.54mm_Vertical
J10: WiFi Jumper; PinHeader_1x02_P2.54mm_Vertical
J11: 12V; PinHeader_2x03_P2.54mm_Vertical
J12: 5V; PinHeader_2x03_P2.54mm_Vertical
J13: Servo; PinHeader_1x03_P2.54mm_Vertical
J14: SR04; PinHeader_1x04_P2.54mm_Vertical
J15: Right wheel sensor; PinHeader_1x03_P2.54mm_Vertical
J16: Rear sensor; PinHeader_1x02_P2.54mm_Vertical
R1, R2, R3: 220; R_Axial_DIN0207_L6.3mm_D2.5mm_P10.16mm_Horizontal
R4: 22K; R_Axial_DIN0207_L6.3mm_D2.5mm_P10.16mm_Horizontal
R5: 10K; R_Axial_DIN0207_L6.3mm_D2.5mm_P10.16mm_Horizontal
R6, R7: 47K; R_Axial_DIN0207_L6.3mm_D2.5mm_P10.16mm_Horizontal
R8, R9, R10, R11: 1K; R_Axial_DIN0207_L6.3mm_D2.5mm_P10.16mm_Horizontal
U1: 3V3; PinHeader_1x03_P2.54mm_Vertical

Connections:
+3V3: C3.1, C5.1, J9.6, J9.7, U1.3 (VOUT)
+5VD: C2.1, C4.1, J4.3 (5V), J5.1 (VCC), J6.1, J7.1 (Vcc), J8.2, J8.8, J12.1, J12.3, J12.5, J13.2 (Vcc), J14.1 (Vcc), J15.1 (Vcc), J16.1, U1.1 (VIN)
+12V: J11.1, J11.3, J11.5, R4.1
GND: C1.2, C2.2, C3.2, C4.2, C5.2, D1.3 (K), D2.1 (K), D3.1 (K), D4.1 (K), D5.1 (K), J4.4 (Gnd), J4.5 (Gnd), J5.2 (GND), J7.2 (Gnd), J8.4, J8.6, J9.2, J11.2, J11.4, J11.6, J12.2, J12.4, J12.6, J13.1 (Gnd), J14.4 (Gnd), J15.2 (Gnd), R5.2, R6.2, R7.2, U1.2 (GND)
unnamed: C1.1, J3.4 (A3), R4.2, R5.1
unnamed: D1.1 (BA), R3.2
unnamed: D1.2 (GA), R2.2
unnamed: D1.4 (RA), R1.2
unnamed: D2.2 (A), R8.2
unnamed: D3.2 (A), R9.2
unnamed: D4.2 (A), R10.2
unnamed: D5.2 (A), R11.2
unnamed: D6.1 (K), J9.5
unnamed: D6.2 (A), J4.1 (Rst)
unnamed: D7.1 (K), J9.8
unnamed: D7.2 (A), J1.2 (Tx)
unnamed: J1.1 (Rx), J10.2
unnamed: J1.3 (D2), J7.3 (D0)
unnamed: J1.4 (D3), J8.7, R10.1
unnamed: J1.5 (D4), R1.1
unnamed: J1.6 (D5), J8.5, R11.1
unnamed: J1.7 (D6), J8.3, R9.1
unnamed: J1.8 (D7), J14.3 (Echo)
unnamed: J2.4 (D11), J8.1, R8.1
unnamed: J2.5 (D12), R2.1
unnamed: J2.6 (D13), R3.1
unnamed: J3.2 (A1), J6.2, R6.1
unnamed: J3.3 (A2), J16.2, R7.1
unnamed: J3.5 (A4), J5.4 (SDA)
unnamed: J3.6 (A5), J5.3 (SCL)
unnamed: J9.1, J10.1
unnamed: J2.2 (D9), J13.3 (PCM)
unnamed: J2.1 (D8), J14.2 (Trig)
unnamed: J2.3 (D10), J15.3 (D0)

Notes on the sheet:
Rear
Left
Front
Right

Board: 2 copper layers, 40 parts (0 on the bottom side), 34 nets, no tracks yet.

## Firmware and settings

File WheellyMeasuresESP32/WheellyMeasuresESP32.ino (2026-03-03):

/*
 * Copyright (c) 2023  Marco Marini, marco.marini@mmarini.org
 *
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
 *    END OF TERMS AND CONDITIONS
 *
 */

/*
   Measure the motor speed.

   Sending command 'start' the robot will move randomly
   and after the test interval (1s) will print the selected motor powers
   and the motor speed measured (pps).
*/

#include <esp_log.h>
static const char* TAG = "WheellyMeasuresESP32";

#include "pins.h"

#include "WiFiModule.h"
#include "Timer.h"
#include "MotorCtrl.h"
#include "Contacts.h"
#include "Display.h"
#include "Tests.h"
#include "MqttClient.h"
#include "LidarServo.h"
#include "Lidar.h"

/*
   Serial config
*/
#define SERIAL_BPS 115200
#define MAX_POWER 255

#define WHEELLY_VERSION "0.10.0"
#define WHEELLY_MESSAGES_VERSION "v0"

static const unsigned WIRE_CLOCK = 400000;

#define inrange(value, min, max) ((value) >= (min) && (value) <= (max))

/*
   Serial line buffer
*/
static const unsigned long SERIAL_TIMEOUT = 2000ul;

/*
   WiFi module
*/
static WiFiModuleClass wiFiModule;

/*
   Motor controllers
*/
MotorCtrl leftMotor(LEFT_FORW_PIN, LEFT_BACK_PIN, LEFT_PIN);
MotorCtrl rightMotor(RIGHT_FORW_PIN, RIGHT_BACK_PIN, RIGHT_PIN);

/*
   Contact sensors
*/
ContactSensors contacts(FRONT_CONTACTS_PIN, REAR_CONTACTS_PIN);

/**
* Configuration store
*/
static ConfStore confStore;

/**
   LCD
*/
static DisplayClass Display;

/*
  Mqqt parameters
*/
static const unsigned long MQTT_RETRY_INTERVAL = 3000ul;
static boolean mqttConnected;
static String deviceId;
static String pubSensorTopic;
static String respCommandTopic;
static String errCommandTopic;
static String subCommandTopics;

static const unsigned long STATUS_INTERVAL = 500ul;

/*
  Lidars
*/
Lidar lidars(FRONT_LIDAR_PIN, REAR_LIDAR_PIN);

/*
  Lidar servo
*/
LidarServo servo(SERVO_PIN);
static const int SERVO_OFFSET = 0;


/*
Test variables
*/
static unsigned long testStartInstant;
static MotorTest leftMotorTest(leftMotor);
static MotorTest rightMotorTest(rightMotor);
static unsigned long leftPulses;
static unsigned long rightPulses;
static bool frontSensor;
static bool rearSensor;
static uint16_t frontDistance;
static uint16_t rearDistance;
static const int MIN_VOLTAGE_VALUE = 1896;
static const int MAX_VOLTAGE_VALUE = 2621;
static int supply;

static Timer statusTimer;

/*
   Set up
*/
void setup() {
  Serial.begin(115200);
  while (!Serial) {
    delay(10);
  }

  Wire.begin();
  Wire.setClock(WIRE_CLOCK);  // 400kHz I2C clock. Comment this line if having compilation difficulties

  // Initialises the configuration store (load the configuration)
  delay(100);
  Serial.println();
  ESP_LOGI(TAG, "Startup sequence");

  Display.begin();
  Display.clear();

  /* Setup supplier sensor */
  pinMode(VOLTAGE_PIN, INPUT);

  ESP_LOGI(TAG, "Initialise confStore");
  confStore.begin();

  ESP_LOGI(TAG, "Initialise wifi module");
  const ConfigRecord& config = confStore.config();
  wiFiModule.begin(config);

  // Initializes the device id and the queue names
  uint64_t mac = ESP.getEfuseMac();
  uint64_t mac1 = 0;
  mac1 |= (mac & 0xffff000000000000ul);
  mac1 |= (mac & 0x0000ff0000000000ul) >> 40;
  mac1 |= (mac & 0x000000ff00000000ul) >> 24;
  mac1 |= (mac & 0x00000000ff000000ul) >> 8;
  mac1 |= (mac & 0x0000000000ff0000ul) << 8;
  mac1 |= (mac & 0x000000000000ff00ul) << 24;
  mac1 |= (mac & 0x00000000000000fful) << 40;

  deviceId = String(mac1, HEX);
  pubSensorTopic = "sens/wheelly/" + deviceId + "/" + WHEELLY_MESSAGES_VERSION + "/test";
  respCommandTopic = "cmd/wheelly/" + deviceId + "/" + WHEELLY_MESSAGES_VERSION + "/test/resp";
  errCommandTopic = "cmd/wheelly/" + deviceId + "/" + WHEELLY_MESSAGES_VERSION + "/test/err";
  subCommandTopics = "cmd/wheelly/" + deviceId + "/" + WHEELLY_MESSAGES_VERSION + "/+";

  ESP_LOGI(TAG, "Initialise mqtt client");
  mqttClient.begin(config.mqttBrokerHost, config.mqttBrokerPort, deviceId, config.mqttUser, config.mqttPsw,
                   subCommandTopics, MQTT_RETRY_INTERVAL);

  mqttClient.onMessage(handleMqttMessage);

  ESP_LOGI(TAG, "Start wifi module");
  wiFiModule.onChange(handleOnChange);
  wiFiModule.start();
  ESP_LOGI(TAG, "Startup sequence completed");

  leftMotor.onSample(handleLeftSensor);
  rightMotor.onSample(handleRightSensor);

  leftMotor.automatic(false);
  leftMotor.asr(false);
  leftMotor.begin();

  rightMotor.automatic(false);
  rightMotor.asr(false);
  rightMotor.begin();

  contacts.onChanged(handleContacts);
  contacts.begin();

  ESP_LOGI(TAG, "Starting status timer");
  statusTimer.interval(STATUS_INTERVAL);
  statusTimer.continuous(true);
  statusTimer.onNext(handleStatus);
  statusTimer.start();

  // Init led
  ESP_LOGI(TAG, "Init status led");
  pinMode(STATUS_LED_PIN, OUTPUT);
  digitalWrite(STATUS_LED_PIN, true);

  /* Setup lidar servo */
  ESP_LOGI(TAG, "Init head servo");
  servo.offset(SERVO_OFFSET);
  servo.begin();
  servo.direction(0, millis());

  /* Setup lidar */
  ESP_LOGI(TAG, "Init lidars");
  lidars.begin();
  lidars.onRange(handleLidarsRange);

  leftMotorTest.onPowerChange(handlePowerChange);
  rightMotorTest.onPowerChange(handlePowerChange);

  ESP_LOGI(TAG, "Wheelly measures started device=%s", deviceId.c_str());
  Display.clear();
  Display.print("Wheelly measures started.");
}

/*
   Main loop
*/
void loop() {
  unsigned long t0 = millis();
  supplyPolling(t0);
  Display.polling(t0);
  wiFiModule.polling(t0);
  servo.polling(t0);
  lidars.polling(t0);
  contacts.polling(t0);
  leftMotor.polling(t0);
  rightMotor.polling(t0);
  mqttClient.polling(t0);
  if (mqttConnected != mqttClient.connected()) {
    mqttConnected = mqttClient.connected();
    Display.connected(mqttConnected);
  }
  leftMotorTest.pooling(t0);
  rightMotorTest.pooling(t0);
  statusTimer.polling(t0);
  Display.move(isTesting());
}

/**
  Polling supply
*/
static void supplyPolling(const unsigned long t0) {
  supply = analogRead(VOLTAGE_PIN);

  /* Computes the charging level */
  const int hLevel = min(max(
                           (int)map(supply, MIN_VOLTAGE_VALUE, MAX_VOLTAGE_VALUE, 0, 10),
                           0),
                         9);
  const int level = (hLevel + 1) / 2;

  /* Display the charging level */
  Display.supply(level);
}

/**
Returns true if test is running
*/
static bool isTesting(void) {
  return leftMotorTest.testing() || rightMotorTest.testing();
}

/**
Sends the report to queue
*/
static void sendReport() {
  // Handles reply to remote controller
  if (mqttClient.connected()) {
    const unsigned long t0 = millis();
    char status[256];
    const bool testing = isTesting();
    sprintf(status, "%lu,%d,%d,%d,%ld,%ld,%d,%d,%u,%u,%d",
            testing ? t0 - testStartInstant : 0l,
            testing,
            leftMotorTest.power(), rightMotorTest.power(),
            leftPulses, rightPulses,
            frontSensor, rearSensor,
            frontDistance, rearDistance,
            supply);
    mqttClient.send(pubSensorTopic, status);
  }
}

/*
Handles status timer
*/
static void handleStatus(void*, const unsigned long) {
  if (!isTesting()) {
    sendReport();
  }
}

/*
Sends command reply
*/
static void sendCommandReply(const String& topic, const String& message) {
  if (mqttClient.connected()) {
    mqttClient.send(topic, message);
  }
}

/*
Handles mqtt message
*/
static void handleMqttMessage(const String& topic, const String& message) {
  ESP_LOGI(TAG, "Message %s %s", topic.c_str(), message.c_str());
  if (topic.endsWith("/test")) {
    startTest(message);
  }
}

static const String validateArguments(const int maxPower, const unsigned long stepUpInterval, const unsigned stepUpPower,
                                      const unsigned long stepDownInterval, const unsigned stepDownPower) {
  if (maxPower == 0 || abs(maxPower) > MAX_POWER) {
    return "Invalid power";
  }
  if (stepUpInterval == 0 || stepDownInterval == 0) {
    return "Invalid interval";
  }
  if (stepUpPower == 0 || stepUpPower > MAX_POWER) {
    return "Invalid acceleration power";
  }
  if (stepDownPower == 0 || stepDownPower > MAX_POWER) {
    return "Invalid deceleration power";
  }
  return "";
}

/*
 Starts the test
*/
static bool startTest(const String& args) {
  if (isTesting()) {
    ESP_LOGE(TAG, "Wrong args %s", args.c_str());
    sendCommandReply(errCommandTopic, "Test is already running");
    return false;
  }
  int count;
  int leftMaxPower;
  unsigned long leftStepUpInterval;
  unsigned leftStepUpPower;
  unsigned long leftStepDownInterval;
  unsigned leftStepDownPower;
  int rightMaxPower;
  unsigned long rightStepUpInterval;
  unsigned rightStepUpPower;
  unsigned long rightStepDownInterval;
  unsigned rightStepDownPower;
  int n = sscanf(args.c_str(), "%d,%lu,%u,%lu,%u,%d,%lu,%u,%lu,%u%n",
                 &leftMaxPower,
                 &leftStepUpInterval,
                 &leftStepUpPower,
                 &leftStepDownInterval,
                 &leftStepDownPower,
                 &rightMaxPower,
                 &rightStepUpInterval,
                 &rightStepUpPower,
                 &rightStepDownInterval,
                 &rightStepDownPower,
                 &count);
  if (n != 10 || count != args.length()) {
    ESP_LOGE(TAG, "Wrong args n=%d count=%d [%s]", n, count, args.c_str());
    sendCommandReply(errCommandTopic, "Wrong args " + args);
    return false;
  }

  // Valudate arguments
  String argError = validateArguments(leftMaxPower, leftStepUpInterval, leftStepUpPower, leftStepDownInterval, leftStepDownPower);
  if (argError != "") {
    ESP_LOGE(TAG, "%s [%s]", argError.c_str(), args.c_str());
    sendCommandReply(errCommandTopic, argError + " " + args);
    return false;
  }

  argError = validateArguments(rightMaxPower, rightStepUpInterval, rightStepUpPower, rightStepDownInterval, rightStepDownPower);
  if (argError != "") {
    ESP_LOGE(TAG, "%s [%s]", argError.c_str(), args.c_str());
    sendCommandReply(errCommandTopic, argError + " " + args);
    return false;
  }

  testStartInstant = millis();
  leftPulses = rightPulses = 0;
  leftMotorTest.start(testStartInstant, leftMaxPower,
                      leftStepUpInterval, leftStepUpPower,
                      leftStepDownInterval, leftStepDownPower);
  rightMotorTest.start(testStartInstant, rightMaxPower,
                       rightStepUpInterval, rightStepUpPower,
                       rightStepDownInterval, rightStepDownPower);

  sendCommandReply(respCommandTopic, args);
  return true;
}

static void handlePowerChange(void*) {
  sendReport();
}

/*
  Handles lidars range
*/
static void handleLidarsRange(void*, Lidar& lidars, const uint16_t frontRange, const uint16_t rearRange) {
  frontDistance = frontRange;
  rearDistance = rearRange;
  uint16_t distance = frontDistance;
  if (rearDistance > 0) {
    if (distance == 0 || rearDistance < distance) {
      distance = rearDistance;
    }
  }
  Display.distance((distance + 5) / 10);
}

/*
   Handles the wifi module state change
*/
static void handleOnChange(void*, WiFiModuleClass& module) {
  char bfr[256];
  boolean connected = module.connected();
  if (connected) {
    mqttClient.connect();
    strcpy(bfr, wiFiModule.ssid().c_str());
    strcat(bfr, " - IP: ");
    strcat(bfr, wiFiModule.ipAddress().toString().c_str());
  } else if (module.connecting()) {
    strcpy(bfr, wiFiModule.ssid().c_str());
    strcat(bfr, " connecting...");
  } else {
    strcpy(bfr, "Disconnected");
  }
  ESP_LOGI(TAG, "%s", bfr);
  Display.clear();
  Display.showWiFiInfo(bfr);
}

static void handleLeftSensor(void*, const int dPulse, const unsigned long clockTime, MotorSensor* sensor) {
  leftPulses += dPulse;
}

static void handleRightSensor(void*, const int dPulse, const unsigned long clockTime, MotorSensor* sensor) {
  rightPulses += dPulse;
}

static void handleContacts(void*, ContactSensors& sensors) {
  frontSensor = sensors.frontClear();
  rearSensor = sensors.rearClear();
  leftMotorTest.stop();
  rightMotorTest.stop();
  block_t block = frontSensor ? rearSensor
                                  ? NO_BLOCK
                                  : BACKWARD_BLOCK
                  : rearSensor
                    ? FORWARD_BLOCK
                    : FULL_BLOCK;
  bool contact = !frontSensor || !rearSensor;
  digitalWrite(STATUS_LED_PIN, contact);
  Display.block(block);
}

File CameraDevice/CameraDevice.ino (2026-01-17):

#include "esp_camera.h"
#include <WiFi.h>

#include "SDConfStore.h"
#include "MqttClient.h"
#include "Camera.h"

#include <esp_log.h>
static const char* TAG = "CameraDevice";

#define CONNECTION_TIMEOUT 10000
#define CONNECTION_INTERVAL 1000
#define WATCHDOG_INTERVAL 30000
#define LOOP_INTERVAL 10
#define DOT_MILLIS 80  // 80 ms =  15 WPM

static const char* WHEELLY_MESSAGES_VERSION = "v0";

SDConfStore confStore;

static boolean mqttConnected = false;
static String pubSensorTopicPrefix;
static String subCommandTopics;
static unsigned long watchdogTime;
static size_t jpgLen = 0;

// static functions
static const String macId(void);
static void onMessage(const String& topic, const String& message);
static void configureCamera(const String& topic, const String& arg);
static const size_t imageCallBack(void* ctx, const size_t index, const byte* data, const size_t len);
static void flashingStarting(void);
static void flashingStarted(void);
static void flashingError(void);

void setup() {
  Serial.begin(115200);
  Serial.println();
  while (!Serial) {}
  delay(500);
  ESP_LOGI(TAG, "Start sequence.");

  ESP_LOGI(TAG, "Configuration store initialisation.");
  confStore.begin();

  // Initializing camrera
  ESP_LOGI(TAG, "Camera initialisation.");
  if (camera.begin()) {
    ESP_LOGE(TAG, "Camera initialisation failed.");
    flashingError();
    ESP.restart();
  }
  // Flashing startup
  flashingStart();

  // Start Wifi
  const char* ssid = confStore.config().wifiSsid.c_str();
  ESP_LOGI(TAG, "Connecting WiFi %s ...", ssid);
  WiFi.begin(ssid, confStore.config().wifiPassword.c_str());
  WiFi.setSleep(false);

  // Wait for connection
  int ct = 0;
  unsigned long timeout = millis() + CONNECTION_TIMEOUT;
  while (WiFi.status() != WL_CONNECTED && millis() <= timeout) {
    vTaskDelay(CONNECTION_INTERVAL / portTICK_PERIOD_MS);
    flashingStarting();
    ESP_LOGI(TAG, "Connecting WiFi...");
  }
  if (WiFi.status() != WL_CONNECTED) {
    ESP_LOGE(TAG, "WiFi connection failed.");
    flashingError();
    ESP.restart();
  }
  ESP_LOGI(TAG, "WiFi connected");

  // Initialize MQTT
  ESP_LOGI(TAG, "Initialise mqtt client");
  const SDConfigRecord& mqttConfig = confStore.config();
  const String id = macId();
  pubSensorTopicPrefix = "sens/wheellycam/" + id + "/" + WHEELLY_MESSAGES_VERSION;
  subCommandTopics = "cmd/wheellycam/" + id + "/" + WHEELLY_MESSAGES_VERSION + "/+";
  ESP_LOGD(TAG, "Subtopics = %s", subCommandTopics.c_str());
  mqttClient.begin(mqttConfig.mqttBrokerHost, mqttConfig.mqttBrokerPort,
                   "wheellycam", mqttConfig.mqttUser, mqttConfig.mqttPsw,
                   subCommandTopics, 3000);
  mqttClient.onMessage(onMessage);

  // Connect MQTT
  ESP_LOGI(TAG, "Mqtt client connecting ...");
  mqttClient.connect();
  flashingStarted();
  ESP_LOGI(TAG, "Start sequence completed.");
}

void loop() {
  unsigned long t0 = millis();
  mqttClient.polling(t0);
  boolean conn = mqttClient.connected();
  if (conn != mqttConnected) {
    mqttConnected = conn;
    ESP_LOGI(TAG, "Mqtt client connected");
    if (conn) {
      mqttClient.send(pubSensorTopicPrefix + "/hi", String(t0));
      watchdogTime = t0 + WATCHDOG_INTERVAL;
    }
  }
  if (t0 >= watchdogTime) {
    mqttClient.send(pubSensorTopicPrefix + "/wu", String(t0));
    watchdogTime = t0 + WATCHDOG_INTERVAL;
  }
  vTaskDelay(LOOP_INTERVAL / portTICK_PERIOD_MS);
}


/**
* Call back jpeg stream
*
* @param ctx context
* @param index index
* @param data data buffer
* @param len data buffer len
*/
static const size_t imageCallBack(void* ctx, const size_t index, const byte* data, const size_t len) {
  if (!index) {
    jpgLen = 0;
  }
  jpgLen += len;
  mqttClient.send(pubSensorTopicPrefix + "/img", data, len);
  ESP_LOGI(TAG, "Jpg chunk index=%lu size=%lu tot%lu", (uint32_t)index, (uint32_t)len, (uint32_t)jpgLen);
  return len;
}

static void configureCamera(const String& topic, const String& arg) {
  char str[100];
  unsigned int ledIntensity, frameSize, count;
  if (sscanf(arg.c_str(), "%u,%u%n", &ledIntensity, &frameSize, &count) != 2 || count != arg.length()) {
    sprintf(str, "Error in message %.40s", arg.c_str());
    ESP_LOGE(TAG, "%s", str);
    mqttClient.send(topic + "/err", str);
    return;
  }
  if (!(frameSize < 13)) {
    sprintf(str, "Wrong frame size %u", frameSize);
    ESP_LOGE(TAG, "%s", str);
    mqttClient.send(topic + "/err", str);
    return;
  }
  if (!(ledIntensity <= 255)) {
    sprintf(str, "Wrong led intensity %u", ledIntensity);
    ESP_LOGE(TAG, "%s", str);
    mqttClient.send(topic + "/err", str);
    return;
  }

  ESP_LOGI(TAG, "Configuration ledIntensity=%u", ledIntensity);
  camera.ledIntensity(ledIntensity);

  const framesize_t framesize = (const framesize_t)frameSize;
  ESP_LOGI(TAG, "Configuration framesize=%u", frameSize);
  esp_err_t res = camera.frameSize(framesize);
  ESP_LOGI(TAG, "Configuration rc=%d", res);
  if (res) {
    sprintf(str, "Error configuring camera rc=%d", res);
    ESP_LOGE(TAG, "%s", str);
    mqttClient.send(topic + "/err", str);
    return;
  }
  mqttClient.send(topic + "/res", arg);
}

static void onMessage(const String& topic, const String& message) {
  ESP_LOGI(TAG, "Message from %s %s", topic.c_str(), message.c_str());
  if (topic.endsWith("/cf")) {
    configureCamera(topic, message);
  } else if (topic.endsWith("/ca")) {
    camera.capture(imageCallBack, 0);
    mqttClient.send(topic + "/res", message);
  }
}

static const String macId(void) {
  uint64_t mac = ESP.getEfuseMac();
  uint64_t mac1 = 0;
  mac1 |= (mac & 0xffff000000000000ul);
  mac1 |= (mac & 0x0000ff0000000000ul) >> 40;
  mac1 |= (mac & 0x000000ff00000000ul) >> 24;
  mac1 |= (mac & 0x00000000ff000000ul) >> 8;
  mac1 |= (mac & 0x0000000000ff0000ul) << 8;
  mac1 |= (mac & 0x000000000000ff00ul) << 24;
  mac1 |= (mac & 0x00000000000000fful) << 40;

  return String(mac1, HEX);
}

static void flashMorse(const char* data) {
  while (*data) {
    switch (*data) {
      case '.':
        camera.flashing(1, 8, DOT_MILLIS, DOT_MILLIS);
        break;
      case '-':
        camera.flashing(1, 8, 3 * DOT_MILLIS, DOT_MILLIS);
        break;
      case ' ':
        vTaskDelay(2 * DOT_MILLIS / portTICK_PERIOD_MS);
        break;
      case '_':
      case '/':
        vTaskDelay(6 * DOT_MILLIS / portTICK_PERIOD_MS);
        break;
    }
    data++;
  }
}

static void flashingError(void) {
  flashMorse("... --- .../... --- .../... --- ...");
}

static void flashingStarting(void) {
  flashMorse(".");
}

static void flashingStarted(void) {
  flashMorse(".-.-.");
}

static void flashingStart(void) {
  flashMorse("-.-.-");
}

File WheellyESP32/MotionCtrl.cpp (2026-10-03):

/*
 * Copyright (c) 2023  Marco Marini, marco.marini@mmarini.org
 *
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
 *    END OF TERMS AND CONDITIONS
 *
 */

#include <esp_log.h>
static char* TAG = "MotionCtrl";

#include "Arduino.h"

#include "MotionCtrl.h"

//#define MONITOR_ON
#include "num.h"
#include "pins.h"

#define SCALE 10000l
#define SPEED_THRESHOLD 0.5f

#define TRACK 0.136f

#define DEG_ANGLE_PER_PULSE (DISTANCE_PER_PULSE / TRACK * 180 / PI)
#define DEFAULT_TAU 300ul

#define MOTOR_SAFE_INTERVAL 2000ul
#define MOTOR_CHECK_INTERVAL 100ul

#define DEFAULT_MIN_ROT_RANGE 3
#define DEFAULT_MAX_ROT_RANGE 30
#define DEFAULT_MAX_ANGULAR_VALUE 10
#define DEFAULT_MAX_SPEED 60
#define DEFAULT_HALT_DISTANCE 20
#define DEFAULT_DECELERATE_DISTANCE 200

#define DEFAULT_P0 27
#define DEFAULT_P1 73
#define DEFAULT_MU 64
#define DEFAULT_AX 1270
#define DEFAULT_H DEFAULT_MU
#define MAX_SPEED 60

/*
  Creates the motion controller
*/
MotionCtrlClass::MotionCtrlClass(const uint8_t leftForwPin, const uint8_t leftBackPin, const uint8_t rightForwPin, const uint8_t rightBackPin, const uint8_t leftSensorPin, const uint8_t rightSensorPin)
  : _leftMotor(leftForwPin, leftBackPin, leftSensorPin),
    _rightMotor(rightForwPin, rightBackPin, rightSensorPin),
    _sensors(_leftMotor, _rightMotor),
    _config({ .minRotRange = DEFAULT_MIN_ROT_RANGE,
              .maxRotRange = DEFAULT_MAX_ROT_RANGE,
              .maxRotPps = DEFAULT_MAX_ANGULAR_VALUE,
              .maxSpeed = DEFAULT_MAX_SPEED,
              .haltDistance = DEFAULT_HALT_DISTANCE,
              .decelerateDistance = DEFAULT_DECELERATE_DISTANCE }),
    _status(MotionStatus::HALT) {

  _sensors.setOnChange([](void* context, unsigned long clockTime, MotionSensor&) {
    ESP_LOGD(TAG, "Motor sensors triggered");
    ((MotionCtrlClass*)context)->handleMotion(clockTime);
  },
                       this);

  _stopTimer.interval(MOTOR_SAFE_INTERVAL);
  _stopTimer.onNext([](void* ctx, unsigned long) {
    ESP_LOGD(TAG, "Stop motor timer triggered");
    ((MotionCtrlClass*)ctx)->halt();
  },
                    this);

  _checkTimer.interval(MOTOR_CHECK_INTERVAL);
  _checkTimer.continuous(true);
  _checkTimer.onNext([](void* ctx, unsigned long) {
    ((MotionCtrlClass*)ctx)->handleMotion(millis());
  },
                     this);
}

/*
  Initializes the motion controller
*/
void MotionCtrlClass::begin() {
  ESP_LOGI(TAG, "Begin");
  _leftMotor.begin();
  _rightMotor.begin();
  _sensors.begin();

  ESP_LOGD(TAG, "Motion controller begin");

  halt();
}

/*
  Resets the controller
*/
void MotionCtrlClass::reset(unsigned long timestamp) {
  ESP_LOGD(TAG, "Reset");
  _sensors.reset(timestamp);
}

/*
  Halt the robot
*/
void MotionCtrlClass::halt() {
  ESP_LOGD(TAG, "Halt");
  _status = HALT;
  motorSpeed(0, 0);
  _stopTimer.stop();
  _checkTimer.stop();
}

/*
  Sets the movement direction and speed
*/
void MotionCtrlClass::rotate(const int direction) {
  ESP_LOGD(TAG, "Rotation %d DEG", direction);
  _direction = direction;
  if (isHalt()) {
    _status = ROTATING;
    _stopTimer.start();
    _checkTimer.start();
    handleMotion(millis());
  } else {
    _stopTimer.restart();
  }
}

/*
  Sets the forward movement
*/
void MotionCtrlClass::forward(const float xTarget, const float yTarget) {
  ESP_LOGD(TAG, "Forward to %.1f, %.1f", xTarget, yTarget);
  _xTarget = xTarget;
  _yTarget = yTarget;
  if (isHalt()) {
    _status = FORWARD;
    _stopTimer.start();
    _checkTimer.start();
    handleMotion(millis());
  } else {
    _status = FORWARD;
    _stopTimer.restart();
  }
}

/*
  Sets the backward movement
*/
void MotionCtrlClass::backward(const float xTarget, const float yTarget) {
  ESP_LOGD(TAG, "Backward to %.1f,%.1f", xTarget, yTarget);
  _xTarget = xTarget;
  _yTarget = yTarget;
  if (isHalt()) {
    _status = BACKWARD;
    _stopTimer.start();
    _checkTimer.start();
    handleMotion(millis());
  } else {
    _status = BACKWARD;
    _stopTimer.restart();
  }
  ESP_LOGD(TAG, "  status=%d", _status);
}

/*
  Configures the controller
  @param p the controller parameters
*/
void MotionCtrlClass::config(const motionConfig_t& cfg) {
  _config = cfg;
}

/*

*/
void MotionCtrlClass::polling(unsigned long clockTime) {
  _stopTimer.polling(clockTime);
  _checkTimer.polling(clockTime);
  _leftMotor.polling(clockTime);
  _rightMotor.polling(clockTime);
  _sensors.polling(clockTime);
}

/*

*/
const boolean MotionCtrlClass::isForward() const {
  return _leftMotor.speed() > 0 || _rightMotor.speed() > 0
         || _sensors.leftPps() > SPEED_THRESHOLD || _sensors.rightPps() > SPEED_THRESHOLD;
}

/*

*/
const boolean MotionCtrlClass::isBackward() const {
  return _leftMotor.speed() < 0 || _rightMotor.speed() < 0
         || _sensors.leftPps() < -SPEED_THRESHOLD || _sensors.rightPps() < -SPEED_THRESHOLD;
}

/*

*/
void MotionCtrlClass::handleMotion(const unsigned long clockTime) {
  unsigned long dt = clockTime - _prevTime;
  _prevTime = clockTime;
  if (dt > 0) {
    ESP_LOGD(TAG, "handleMotion %lu status=%d", clockTime, _status);
    // motion not yet handled
    switch (_status) {
      case FORWARD:
        handleForward();
        break;
      case BACKWARD:
        handleBackward();
        break;
      case ROTATING:
        handleRotation();
        break;
      default:
        break;
    }
  }
}

/**
 Returns the rotation speed
 @param angle rotation angle (DEG)
 @param config motion configuration
*/

static int computeRotSpeed(const int angle, const motionConfig_t& config) {
  int speed = config.maxRotPps;
  const int absTurn = abs(angle);
  if (absTurn <= config.maxRotRange) {
    // Approching target direction
    // Compute approaching speed
    ESP_LOGD(TAG, "Approaching target direction %d DEG (actual %d DEG)", _direction, dir1);
    speed = map(absTurn, 0, config.maxRotRange, 0, config.maxRotPps);
  }
  ESP_LOGD(TAG, "Speed %d", speed);
  return angle < 0 ? -speed : speed;
}

/**
  Computes the left and right motor speed from linera speed and rotation speed
  @param left left motor speed output value
  @param right motor speed output value
  @param speed the linear speed (pps)
  @param rotSpeed the rotation spped (pps)
*/
static void computeMotorSpeed(int& left, int& right, const int speed, const int rotSpeed) {
  left = 0;
  right = 0;
  int max = abs(speed) + abs(rotSpeed);
  int rel = min(max, MAX_SPEED);
  left = (speed + rotSpeed) * rel / max;
  right = (speed - rotSpeed) * rel / max;
}
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

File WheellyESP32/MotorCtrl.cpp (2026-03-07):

/*
 * Copyright (c) 2023  Marco Marini, marco.marini@mmarini.org
 *
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
 *    END OF TERMS AND CONDITIONS
 *
 */

#include <esp_log.h>
static char* TAG = "MotorCtrl";

#include "Arduino.h"

#include "MotorCtrl.h"

#include "num.h"
#include "pins.h"

#define DEFAULT_TAU 300ul
#define DEFAULT_ASR 200
#define DEFAULT_PWM_FACTOR 1400
#define DEFAULT_MAX_PULSE_INTERVAL 200
#define DEFAULT_LAMBDA_FACTOR 10
#define DEFAULT_DELAYED_INTERVAL 10

static int MAX_PWM = 255;
static long ASR_SCALE = 1000;

/**
Handles the pulse from sensor
*/
void handlePulses(void* context, const int pulses, const unsigned long t, MotorSensor* sensor) {
  MotorCtrl* controller = (MotorCtrl*)context;
  controller->onPulses(pulses, t);
}

/*
   Creates the motor controller
*/
MotorCtrl::MotorCtrl(const uint8_t forwPin, const uint8_t backPin, const uint8_t sensorPin)
  : _forwPin(forwPin),
    _backPin(backPin),
    _status(MOTOR_HALT),
    _sensor(sensorPin),
    _automatic(true),
    _asr(true),
    _fPwmFactor(DEFAULT_PWM_FACTOR),
    _bPwmFactor(-DEFAULT_PWM_FACTOR),
    _tcs({ .asr = DEFAULT_ASR,
           .maxPulseInterval = DEFAULT_MAX_PULSE_INTERVAL,
           .lambdaFactor = DEFAULT_LAMBDA_FACTOR,
           .delayedInterval = DEFAULT_DELAYED_INTERVAL }) {
}

/*
   Initializes motor controller
*/
void MotorCtrl::begin() {
  ESP_LOGI(TAG, "Begin");
  pinMode(_forwPin, OUTPUT);
  pinMode(_backPin, OUTPUT);
  _sensor.begin();
  _sensor.onSample(handlePulses, this);
}

/*
  Returns the target pwm
  */
const int MotorCtrl::computePwm(void) const {
  int pwm = (_speed > 0
               ? _fPwmFactor
             : _speed < 0
               ? _bPwmFactor
               : 0)
            / (long)_pulseInterval;
  return constrain(pwm, -MAX_PWM, MAX_PWM);
}

/**
  Returns the power factor
  @param pulseWidth the pulse width (ms)
*/
void MotorCtrl::updatePwmFactor(const long pulseWidth) {
  // Compute factor with last pulse width
  ESP_LOGD(TAG, "Update for pulse width %lu", pulseWidth);
  long pwmFactor = pulseWidth > 0 ? _pwm * pulseWidth : _pwm;
  if (pwmFactor == 0) {
    pwmFactor = _pwm > 0 ? 1 : -1;
  }
  // Average with previous value
  ESP_LOGD(TAG, "Update pwmFactor from %ld, %ld with %ld", _fPwmFactor, _bPwmFactor, pwmFactor);
  if (_pwm > 0) {
    _fPwmFactor = _fPwmFactor * (100 - _tcs.lambdaFactor) + pwmFactor * _tcs.lambdaFactor;
    _fPwmFactor /= 100;
  } else {
    _bPwmFactor = _bPwmFactor * (100 - _tcs.lambdaFactor) + pwmFactor * _tcs.lambdaFactor;
    _bPwmFactor /= 100;
  }
  ESP_LOGD(TAG, "                   to %ld, %ld", _fPwmFactor, _bPwmFactor);
}

/**
   Sets the pwm factor
  */
void MotorCtrl::pwm(const int pwm, const unsigned long t) {
  _targetPwm = pwm;
  ESP_LOGD(TAG, "target pwm = %d", pwm);
  if (!_asr || pwm == 0) {
    // immediate pwm if no asr or motor halt
    applyPwm(pwm, t);
  }
}

/*
   Applies the power to the motor
   @param pwr the power -255 ... 255
*/
void MotorCtrl::applyPwm(const int pwm, const unsigned long t0) {
  ESP_LOGD(TAG, "pwm=%d", pwm);
  if (_pwm != pwm || pwm == 0) {
    _lastPwmTime = t0;
  }
  _pwm = pwm;
  _sensor.direction(pwm);
  // Applies the power
  if (pwm == 0) {
    analogWrite(_forwPin, 0);
    analogWrite(_backPin, 0);
  } else if (pwm > 0) {
    analogWrite(_forwPin, pwm);
    analogWrite(_backPin, 0);
  } else {
    analogWrite(_forwPin, 0);
    analogWrite(_backPin, -pwm);
  }
}

/*
   Sets the motor speed
*/
void MotorCtrl::speed(const int value) {
  ESP_LOGD(TAG, "speed(%d)", value);
  const unsigned long t = millis();
  if (value == 0
      || _speed < 0 && value > 0
      || _speed > 0 && value < 0) {
    // Speed == 0 or speed direction != current speed: halt motor
    _status = MOTOR_HALT;
    _speed = 0;
    pwm(0, t);
    ESP_LOGD(TAG, "Stop motor");
  } else if (_speed == 0) {
    // motor stopped
    _status = MOTOR_STARTING;
    // set speed
    _speed = value;
    // set expected pulse interval
    _pulseInterval = 1000 / abs(value);
    // set last pulse time
    _lastPulsesTime = t;
    // Compute initial pwm and apply immediate
    int pwm = computePwm();
    ESP_LOGD(TAG, "Start pwm=%d pulseInterval=%lu", pwm, _pulseInterval);
    this->pwm(pwm, t);
  } else {
    // Change speed and pulse interval
    _speed = value;
    _pulseInterval = 1000 / abs(value);
    ESP_LOGD(TAG, "Change speed pulseInterval=%lu", _pulseInterval);
  }
}

/*
  Polls the motor controller
*/
void MotorCtrl::polling(const unsigned long t) {
  _sensor.polling(t);

  switch (_status) {
    case MOTOR_STARTING:
      starting(t);
      break;
    case MOTOR_RUNNING:
      running(t);
      break;
  }
  // Regulate pwm with anti-slip regulation
  if (_targetPwm != _pwm) {
    // computes the interval since last pwm
    long dt = t - _lastPwmTime;
    // Check for time elapsed
    if (dt > 0) {
      // compute the maximum pwm change
      int dpMax = _tcs.asr * dt / ASR_SCALE;
      // Compute the next pwm (absolute value)
      int newAbsPwm = min(abs(_targetPwm), abs(_pwm) + dpMax);
      if (dpMax > 0 && newAbsPwm != abs(_pwm)) {
        ESP_LOGD(TAG, "ASR: dt=%lu dpMax=%d, newAbsPwm=%d targetPwm=%d", dt, dpMax, newAbsPwm, _targetPwm);
        // pwm change valid
        applyPwm(_targetPwm > 0 ? newAbsPwm : -newAbsPwm, t);
        // store change pwm instant
        _lastPwmTime = t;
      }
    }
  }
}

/*
  Handling polling during starting status
*/
void MotorCtrl::starting(const unsigned long t) {
  long pulseInterval = t - _startTime;
  if (pulseInterval > _pulseInterval) {
    // no pulse detected (no motion)
    // Incremet pwm
    pwm(_speed > 0 ? MAX_PWM : -MAX_PWM, t);
  }
}

/*
  Handling polling during running status
*/
void MotorCtrl::running(const unsigned long t) {
  long dt = t - _lastPulsesTime;
  if (dt > _tcs.maxPulseInterval) {
    // no pulse detected (no motion)
    ESP_LOGD(TAG, "no pulses dt=%ul pulseInterval=%lu", dt, _pulseInterval);
    // Incremet pwm
    ESP_LOGD(TAG, "Starting motor");
    _status = MOTOR_STARTING;
    _startTime = t;
    pwm(computePwm(), t);
  } else if (dt > _pulseInterval && (t - _lastDelayedTime) > _tcs.delayedInterval) {
    // Delayed pulse
    ESP_LOGD(TAG, "delayed pulse dt=%ul pulseInterval=%lu", dt, _pulseInterval);
    _lastDelayedTime = t;
    updatePwmFactor(dt);
    pwm(computePwm(), t);
  }
}
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

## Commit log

2022-06-18 Imported KC folder
    [motor-driver-0.kicad_pcb, motor-driver.kicad_pcb, motor-driver.kicad_sch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]
2022-07-14 Changed startup led sequence and output wifi IP Address #5
2022-09-12 Issue #1: status led for default access point
2023-01-01 Squashed commit of the following:
    commit 675f6ed85ed7138b55e524eea166590810c414db
    Author: mmarini <marco.marini@mmarini.org>
    Date: Sun Jan 1 23:26:21 2023 +0100
    changelog
    commit d4c45f285577b641f5c4358d7b80246b7f26a76f
    Author: mmarini <marco.marini@mmarini.org>
    Date: Sun Jan 1 23:23:28 2023 +0100
    handle imu failure
2023-01-08 Motor configuration command integer motor power minimal conversion location and speed sensor minimal conversion of contact sensors minimal conversion of distance, voltage
2023-01-17 Change WheellyMeasures #22
2023-01-20 motor supply at 12V and configuration command
2023-01-20 Change motor power supply and add controller configurations
2023-02-07 Set contact sensors thresholds
2023-02-09 Issue #34: Change WheellyMeasures to run ramp power measures
2023-02-10 Managing stiction in motor controller
2023-02-11 Issue #36: Change motor controller to manage stiction
2023-02-12 Issue #42: Merge filter and speedmeter
2023-02-12 Issue #44: Add power acceleration limits
2023-02-22 Added bland and new base
    [Base.dxf, wheelly.blend]
2023-02-24 Blender model
    [ArduinoBoard.blend, Base.blend, Breadboard.blend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]
2023-08-08 Command interpreter esp32 and tests wheellino-2.0 Changed base
    [Base.blend, Contacts.dxf, wheellino-esp32.kicad_pcb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]
2023-08-10 Esp32 board
    [wheellino-esp32.kicad_pcb, wheellino-esp32.kicad_sch]
2023-08-22 Fixed pcb error
    [wheellino-esp32.kicad_pcb]
2023-10-13 Issue #55: Add configure proxy scan interval
    [Wheelly.cpp]
2023-10-16 yaw drift
2023-10-16 Issue #69: Add physic measures
    [Contacts.cpp, MotorCtrl.cpp, WheellyMeasuresESP32.ino]
2023-10-17 Issue #71: Change measures with power ramp up and down
    [WheellyMeasuresESP32.ino]
2023-10-17 Issue #73: Fix report with start and stop test records
    [WheellyMeasuresESP32.ino]
2023-10-20 Issue #75: Change motion by mixing rotation and movement
    [MotionCtrl.cpp]
2023-10-20 Issue #78: Add friction test
    [WheellyMeasuresESP32.ino]
2023-10-22 Remove arduino one board code #82
2023-10-31 Issue #84: Add battery level icons
    [LCDTest.ino, Wheelly.cpp]
2023-11-07 Issue #86: Add proxy sensor noise filter
    [Wheelly.cpp]
2023-11-12 #88: Fix status send frequence on move (TCS review)
    [MotionCtrl.cpp, MotorCtrl.cpp, MotorsTest.ino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]
2023-11-14 Issue #91: Change LED status flashing
    [Wheelly.cpp]
2023-11-17 Issue #93: Switch on LED utill start
    [MotionCtrl.cpp, Wheelly.cpp]
2023-12-05 #95: Unexpetcted restart on servo movement
2023-12-11 smooth servo new comamnd interpreter async status messages
2023-12-14 Issue #98: Add asyncronous status messages
    [MotorsTest.ino, ProxySensor.cpp, Wheelly.cpp]
2024-08-22 Add web camera #107
    [webcam.kicad_pcb, webcam.kicad_sch]
2025-06-29 flashing cam LED
2025-07-17 esp32 board 3.2.1
2025-08-24 morse led signal mqtt camera, esp log, cvs arguments MQTT CameraDevice sketch iot topics design
2025-11-06 flip camera image Lidar signals LidarServo head cad projects Add lidar
    [Cam.blend, CamBoards.blend, Head-print.blend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]
2025-12-22 changed motor controller
2025-12-23 Mqtt Wheelly measures
2025-12-27 Added lidars and changed parameters validation
2026-01-17 Add SD Camera Card and change motor controller by voltage
2026-02-08 add head rotasion limits and changed servo controller
2026-02-26 Update CHANGELOG for version 0.10.0
    Added new version 0.10.0 with Lidar sensors and test record.
2026-03-03 motor controlled by pulse width go commands
2026-10-28 removed String removed CameraWebServer and add config.json template
2026-11-01 Reduce camera device hearbeat interval
